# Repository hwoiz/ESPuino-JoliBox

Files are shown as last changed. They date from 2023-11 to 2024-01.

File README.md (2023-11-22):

# Jolibox
## Ein mit RFID-Karten steuerbarer Audioplayer
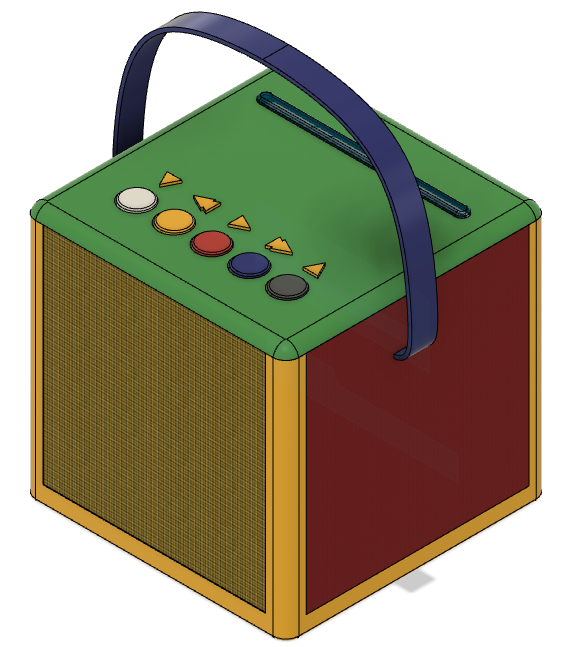
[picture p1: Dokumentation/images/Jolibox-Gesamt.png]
Jolibox


Auf Bais der [Software ESPuino](https://forum.espuino.de/c/software/7) und der [Hardware (ESPuino-mini 4Layer + D32 pro FePo)](https://forum.espuino.de/t/espuino-mini-4layer/1661) von [biologist79](https://github.com/biologist79/ESPuino) habe ich einen kindgerechten Auidioplayer entwickelt. 

Die Druckdateien für das Gehäuse wurden mit der kostenlosen Version von Fusion 360 erstellt und anschließend mit einem 3D-Drucker ausgedruckt. So entstand ein 'kinderleicht' zu bedienender Audioplayer für meine 2-jährige Enkeltochter. Die Titelauswahl kann sie mit den programmierten RFID-Karten selbst vornehmen. 

Die gesamte Administration des Audioplayers erfolgt über eine Webseite mit einem beliebigen Browser durch die Eltern.

---

- [Benutzerhandbuch](Dokumentation/Benutzerhandbuch.md)
- [Technikhandbuch](Dokumentation/Technikhandbuch.md)
- [Gehäuse Konstrutiondaten](Dokumentation/Gehäuse.md)
- [Deutsche Übersetzung der README.md aus dem biologist79-Repository](Dokumentation/README.md-biologist.md)

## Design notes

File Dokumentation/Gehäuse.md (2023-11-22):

# Gehäuse
Um die Elektronik ansprechend und kindgerecht zu verpacken, wurde ein Gehäuse für den 3D-Druck entwickelt.
JoliBox

Die zum Druck notwendigen STL-Dateien wurden mit der Lizenz von Fusion 360 für Privatanweder erstellt. Diese kann nach einer Registrierung [hier](https://www.autodesk.de/products/fusion-360/personal-form) kostenlos heruntergeladen werden.

Zur leichteren Verschraubung der Bauteile wurden in die vorgesehenen Löcher M3-Messing-Einpressmuttern ([z.B. Amazon-Link](https://www.amazon.de/STCRERAG-Gewindeeinsatz-Einpressmutter-Schmelzgewinde-Kunststoffteile/dp/B095VW7GBW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)) mit dem Lötkolben eingeschmolzen. 

Die vollständigen Konstruktionsdaten zum Import in Fusion 360 stelle ich [hier](Gehäuse/ESPuino-Jolibox.f3z) zur Verfügung. Dort kann dann die Konstruktion der Box an die eigenen Wünsche angepasst werden.

Der Druck erfolgte mit PLA auf einem Anycubic i3 Mega. 

Falls die Box ohne Anpassungen gedruckt werden soll, stelle ich nachfolgend die dafür notwendigen STL-Dateien zur Verfügung. Sie müsen noch für den verwendeten 3D-Drucker in gcode-Dateien umgewandelt werden. Hierfür kann die kostenlose Software [Cura](https://ultimaker.com/software/ultimaker-cura/) oder [PrusaSlicer](https://www.prusa3d.com/de/page/prusaslicer_424/) verwendet werden.

### Box Unterteil
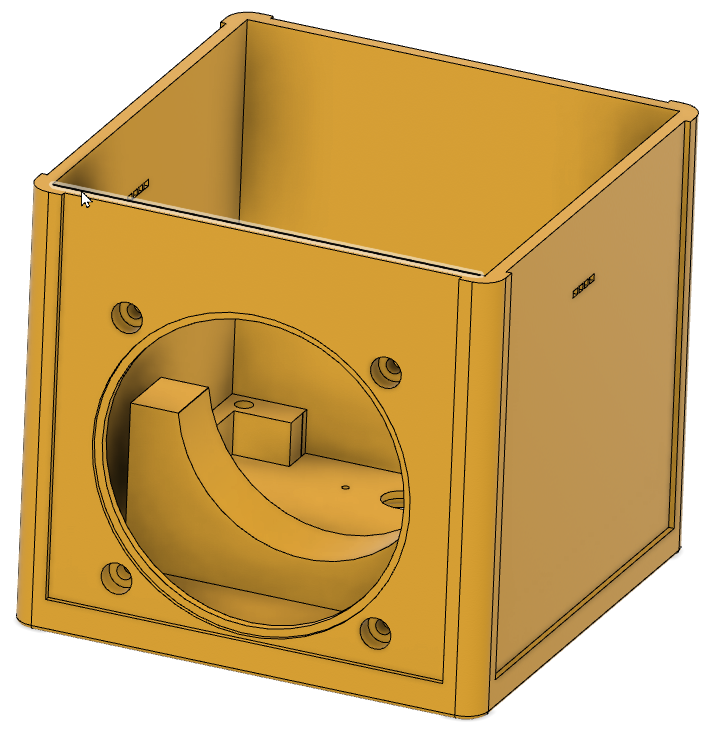
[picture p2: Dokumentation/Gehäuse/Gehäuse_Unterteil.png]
Box-Unterteil

>[Gehäuse_Unterteil.stl](Gehäuse/Gehäuse_Unterteilteil.stl)

> :information_source: Die vier senkrechten Seiten der Box wurden mit 1mm starkem, farblich unterschiedlichem Filz beklebt ([z.B. Amazon-Link](https://www.amazon.de/gp/product/B01MDNM6D7/ref=ppx_yo_dt_b_search_asin_title?ie=UTF8&psc=1)). Der Filz wurde mit Sprühkleber befestigt. 
> Alternativ können auch entsprechende Abdeckungen mit dem 3D-Drucker erstellt werden. 
 
 ---
### Box Oberteil
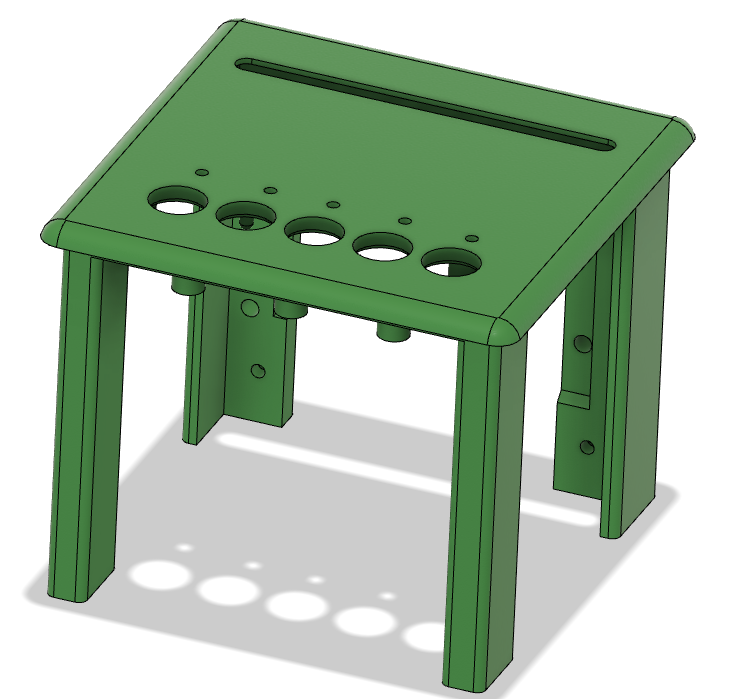
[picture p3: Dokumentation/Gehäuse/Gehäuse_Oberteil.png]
Box-Oberteil

>[Gehäuse_Oberteil.stl](Gehäuse/Gehäuse_Unterteilteil.stl)

---
### LED-Halter
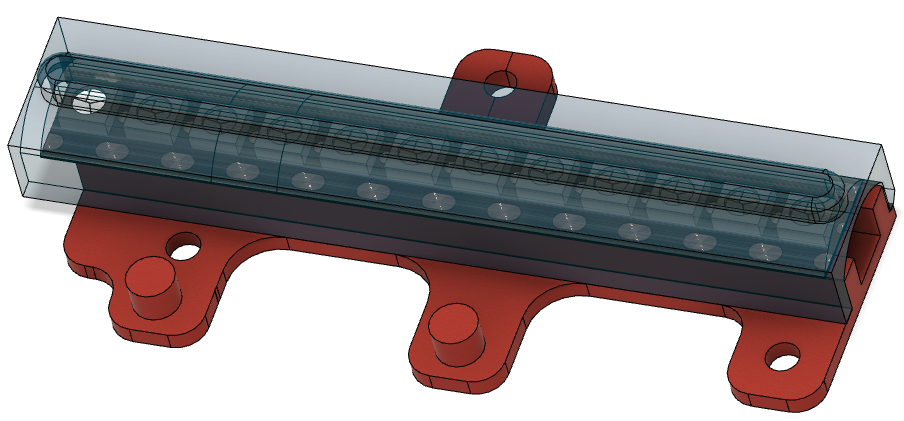
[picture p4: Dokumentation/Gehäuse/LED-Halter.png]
LED-Halter

>[LED-Halter-Aussen.stl](Gehäuse/LED-Halter-Aussen.stl) -  :warning: Transparentes PLA verwenden

>[LED-Halter-Deckel.stl](Gehäuse/LED-Halter-Deckel.stl)

Der Halter nimmt einen Abschnitt von 12 LED eines RGB LED-Streifen WS2812B mit 144 LED/m auf ([z.B. Amazon-Link](https://www.amazon.de/gp/product/B08P6XN49P/ref=ppx_yo_dt_b_search_asin_title?ie=UTF8&psc=1)).

---
### Tastatur-Halter
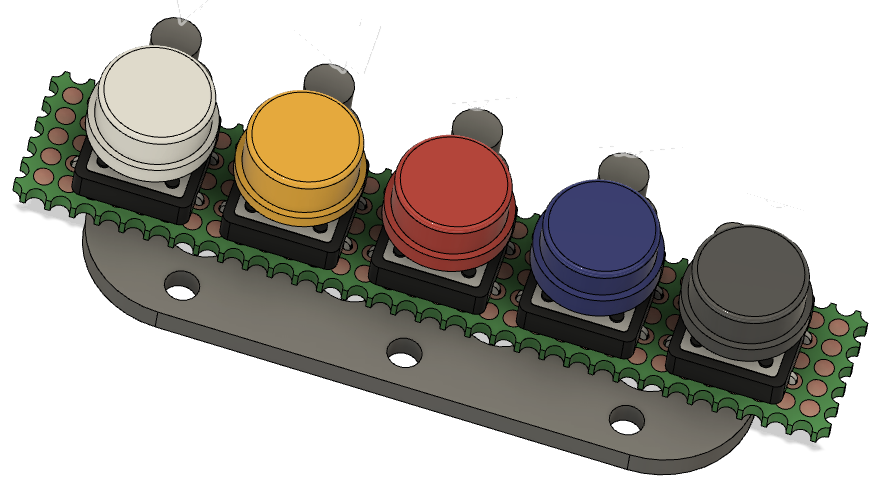
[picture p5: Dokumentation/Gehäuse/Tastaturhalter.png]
Tastatur-Halter

>[Tastaturhalter.stl](Gehäuse/Tastaturhalter.stl)

---
### Tastatur-Symbole
Tastatur-Symbole
>[Symbole.stl](Gehäuse/Symbole.stl)

---
### Tragegurtverschluss
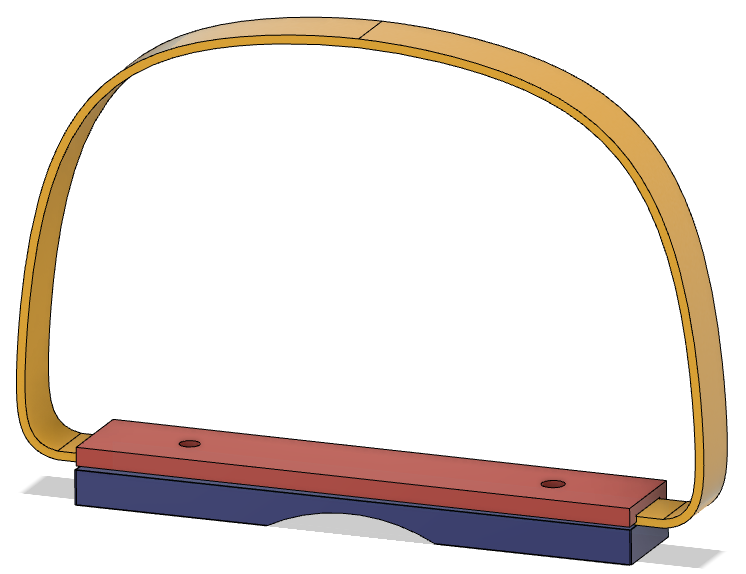
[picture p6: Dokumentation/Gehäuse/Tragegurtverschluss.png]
Tragegurtverschluss

>[Tragegurtverschluss-oben.stl](Gehäuse/Tragegurtverschuss-oben.stl)

>[Tragegurtverschluss-unten.stl](Gehäuse/Tragegurtverschluss-unten.stl)

> :information_source: Für den Tragegurt wurde farbiges Gurtband von 10mm Breite und 1,5mm Stärke benutzt ([z.B. Amazon-Link](https://www.amazon.de/gp/product/B0BNJCMKBM/ref=ppx_yo_dt_b_search_asin_title?ie=UTF8&psc=1)).

---
### Träger-Stromversorgung
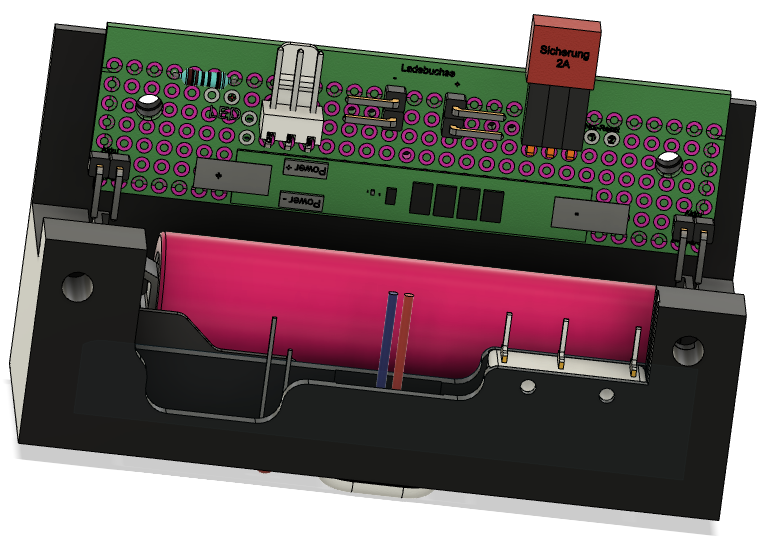
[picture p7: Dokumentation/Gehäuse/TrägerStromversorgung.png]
Träger-Stromversorgung

>[TrägerStromversorgung.stl](Gehäuse/TrägerStromversorgung.stl)

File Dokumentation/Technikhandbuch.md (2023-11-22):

# Technikhandbuch
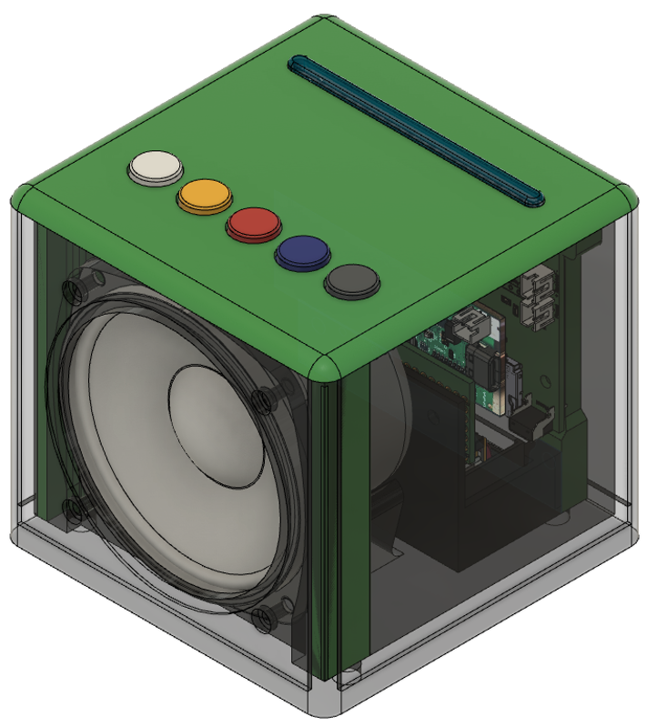
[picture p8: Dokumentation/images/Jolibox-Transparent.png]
Jolibox


Harald Woizischke
info@woizischke.de

Technische Beschreibung einer Kinder-Musikbox auf Basis eines ESP32. 
Kinder können die Musik oder Hörspiele mit Rfid-Tags auswählen.
Die Konfiguration der Box erfolgt über eine Webschnittstelle im Browser.

# Einleitung
Dieses Dokument beschreibt alle zum Bau notwendigen Komponenten.
Die Gehäuseteile wurden mit Autocad Fusion 360 entworfen und mit einem 3D-Drucker in PLA gedruckt.
Als Systemplattform wurde die Lösung von Torsten Stauder (biologist) gewählt. Einzelheiten zum Projekt sind im Internet unter https://forum.espuino.de/ zu finden.

# Hardware
## Elektronik Baugruppen
Es wurden folgende Baugruppen und Bauteile zur Realisierung eingesetzt.
- ESPuino-mini 4Layer von biologist - https://forum.espuino.de/t/espuino-mini-4layer/1661/1
- D32 pro FePo. von biologist - https://forum.espuino.de/t/develboard-d32-pro-lifepo4/1109
- Tastatur auf Lochrasterplatine. Tasten aus Set - https://de.aliexpress.com/item/1005003510575948.html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
- Akku 18650 3.2V 2.000mAh LiFePO4 - https://www.eremit.de/p/18650-3-2v-2-000mah-lifepo4
- Zusatzplatine für Akkuhalterung auf Lochrasterplatine
- Visaton vs-f8sc/8 Lautsprecher - https://www.amazon.de/dp/B0056BQXCW?psc=1&ref=ppx_yo2ov_dt_b_product_details
- RFID-Reader RC522
- 12 LED aus 5v RGB LED-Streifen WS2812B 144 Pixel/m - https://www.amazon.de/gp/product/B08P6XN49P/ref=ppx_yo_dt_b_search_asin_title?ie=UTF8&psc=1 
- 3mm LED rot für Ladeanzeige
- USB-C Ladebuchse - https://de.aliexpress.com/item/1005004913934656.html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
- Micro-Switch für Not-Reset - https://www.amazon.de/VILLCASE-Endschalter-Scharnierhebel-Steuerung-Mikroschalter/dp/B08H52SDG2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 
- Amazon BASIC PLA - https://www.amazon.de/gp/product/B07CTQDQ77/ref=ppx_yo_dt_b_search_asin_title?ie=UTF8&psc=1

## ESPuino-mini_4Layer
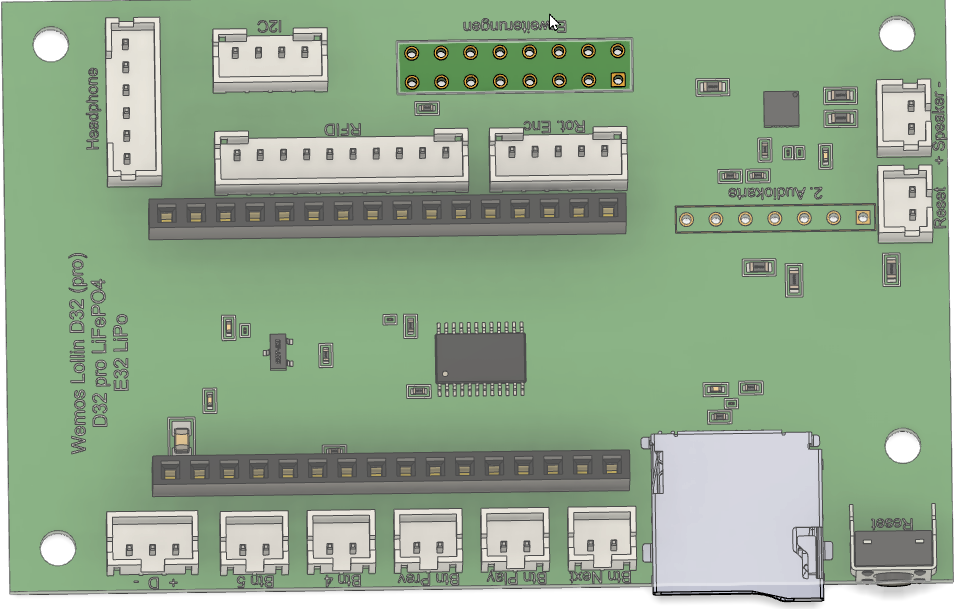
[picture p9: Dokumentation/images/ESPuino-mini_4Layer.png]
ESPuino-mini_4Layer
 
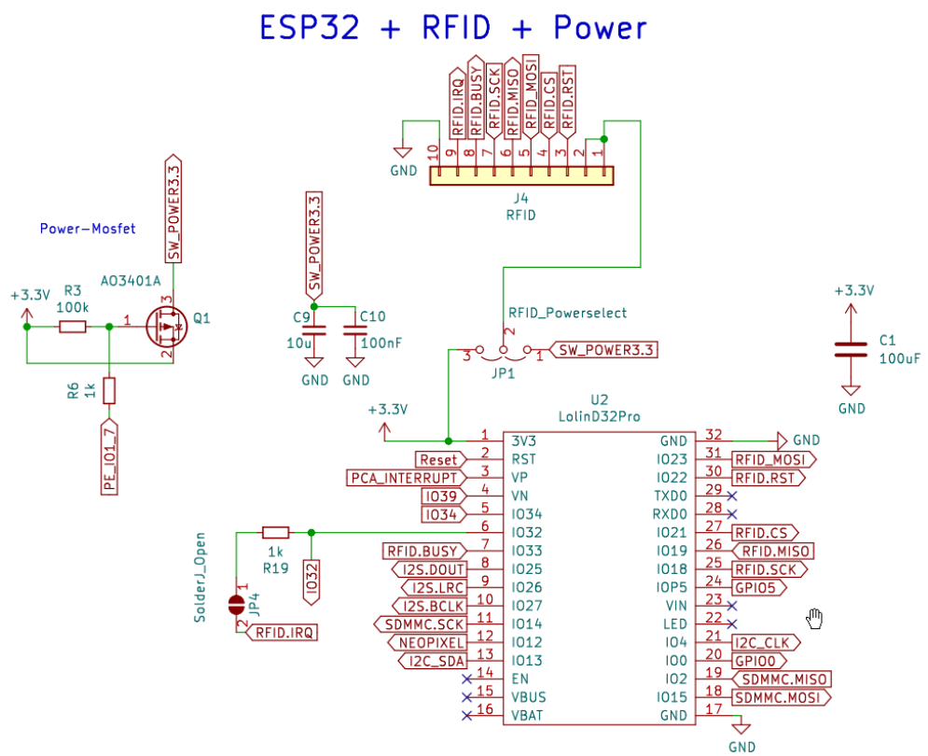
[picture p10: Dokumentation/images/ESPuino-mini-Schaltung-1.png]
Espuino-mini_1
 
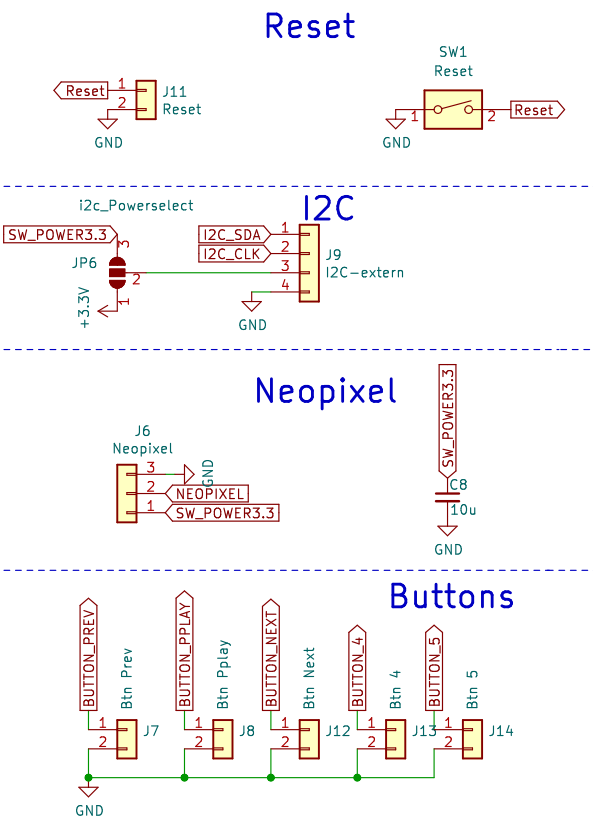
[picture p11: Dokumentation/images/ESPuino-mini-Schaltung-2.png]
Espuino-mini_2
 
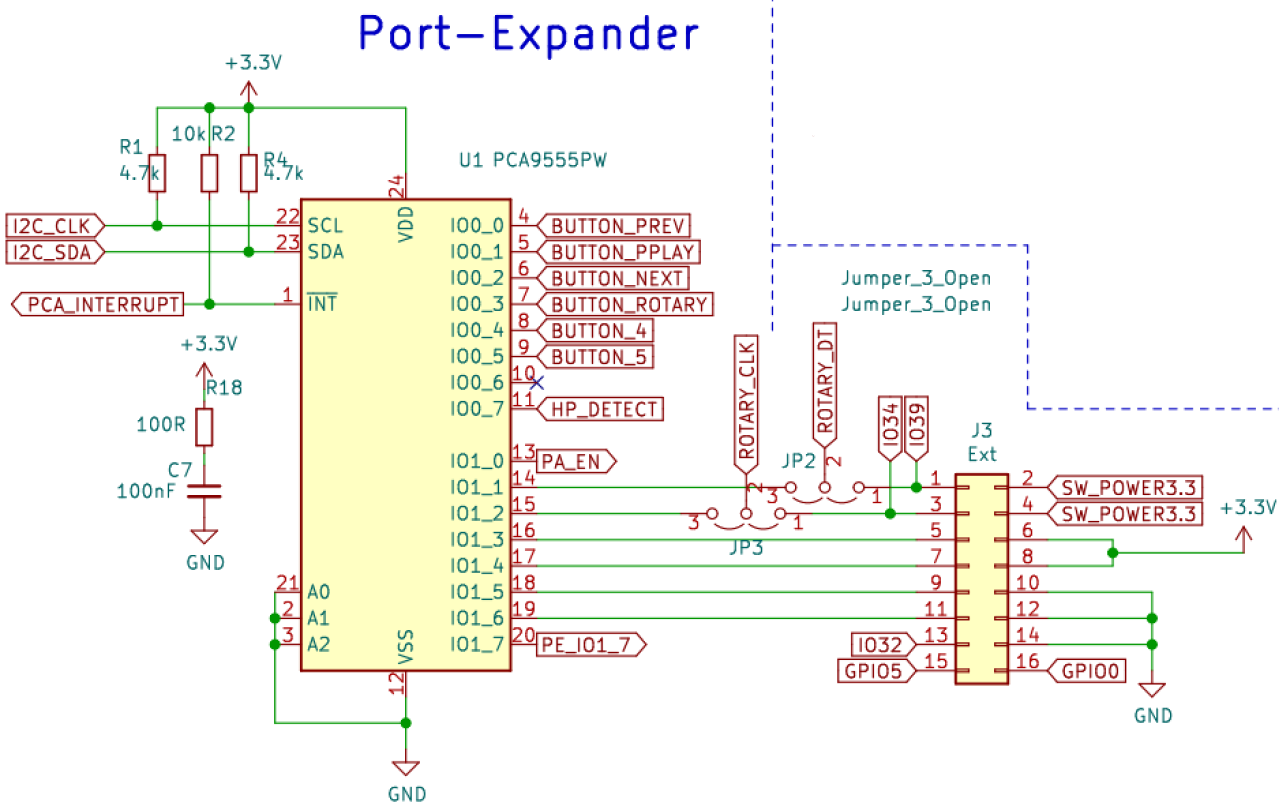
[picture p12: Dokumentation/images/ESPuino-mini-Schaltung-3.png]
Espuino-mini_3
 
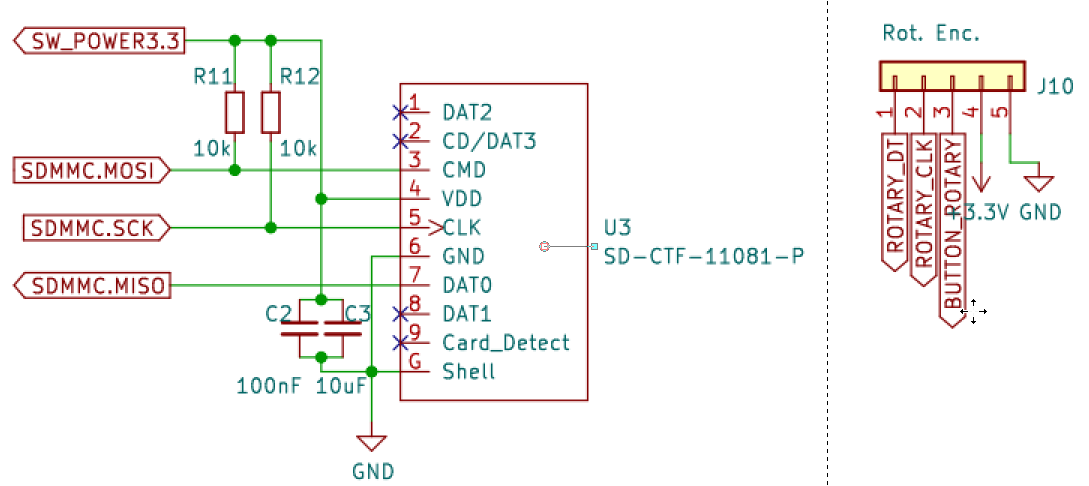
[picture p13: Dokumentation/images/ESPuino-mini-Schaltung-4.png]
Espuino-mini_4
 
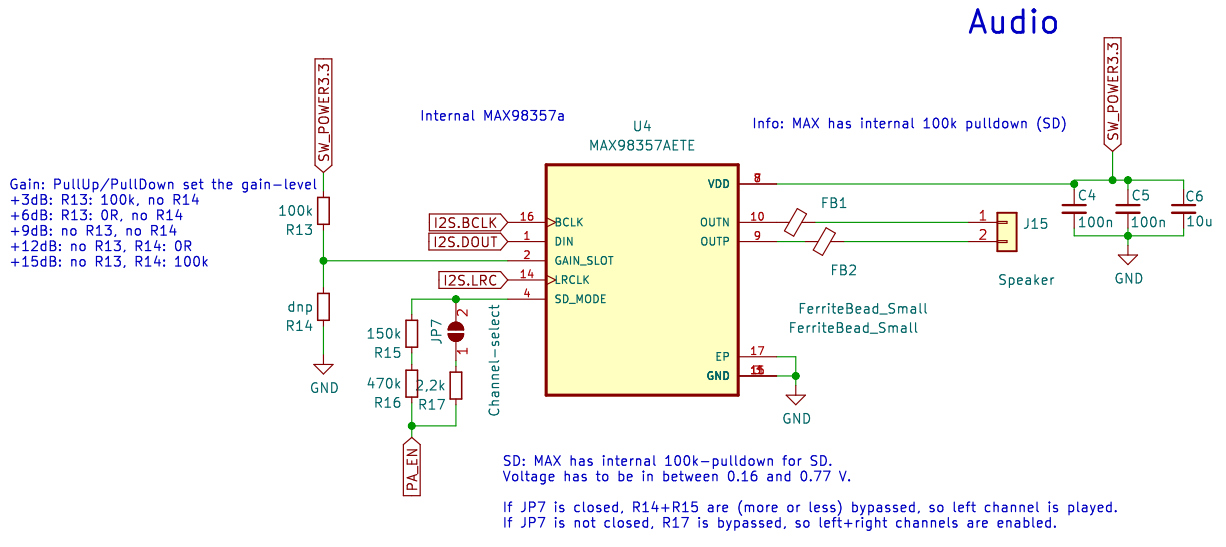
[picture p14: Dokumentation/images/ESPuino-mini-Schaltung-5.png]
Espuino-mini_5
 
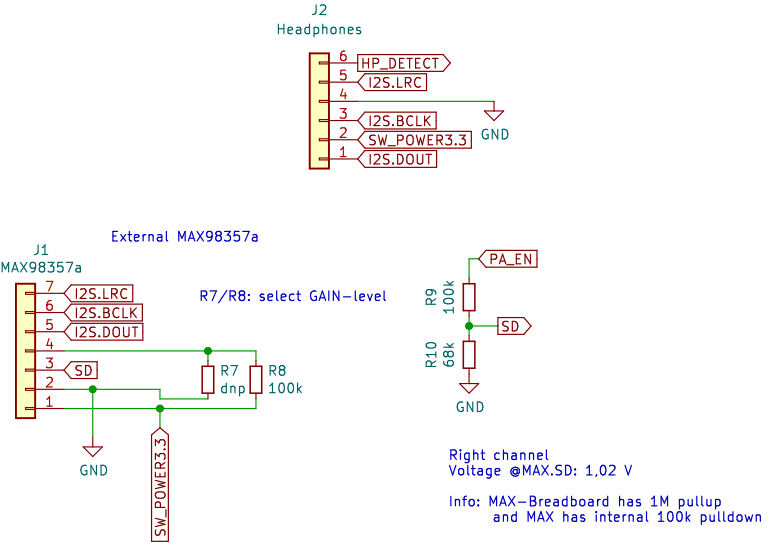
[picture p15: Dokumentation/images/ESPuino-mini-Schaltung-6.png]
Espuino-mini_6
 
 ** Hardware Konfiguration **
Auf Unterseite der Platine befinden sich mehrere Lötbrücken (JP1 bis JP7, JP5 fehlt), die konfiguriert werden können bzw. müssen. Sie werden im Folgenden beschrieben. Kursiv markiert ist die Konfiguration, die aus meiner Sicht „standard“ ist (sofern anwendbar):
JP1: *Schließe* 1+2 wenn du kein LPCD benötigst (Normalzustand). Schließe 2+3, wenn du LPCD benötigst. Auswirkung: Für LPCD wird das RFID-Modul dauerhaft mit Spannung versorgt, so dass eine etwas höhere Stromaufnahme im Deepsleep anfällt. Vergisst du JP1 komplett, so wird dein RFID-Reader nicht funktionieren, da er (egal wann) keine Versorgungsspannung erhält. Hinweis: Willst du dieses Feature nutzen, dann musst du auch die Brücke von JP4 schließen. Sollte dir unklar sein, was LPCD bedeutet, so findest du hier die Erklärung: 📗 [Was ist LPCD und wie funktioniert es?](https://forum.espuino.de/t/was-ist-lpcd-und-wie-funktioniert-es/1664).
**Pflicht!**
JP2: *Schließe* 1+2 wenn DT des Drehencoders auf GPI(O)39 geroutet werden soll. Schließe 2+3, wenn GPIO39 frei sein soll und DT stattdessen auf dem Port-Expander (109) landen soll. Stand jetzt (01/2023) macht ausschließlich GPIO Sinn, da ESPuino hier den Port-Expander noch nicht unterstützt. Vergisst du JP2 komplett, so funktioniert die Drehbewegung deines Drehencoders nicht (sofern du diesen verwendest).
**Pflicht wenn ein Drehencoder verwendet wird!**
JP3: Schließe 1+2 wenn CLK des Drehencoders auf GPIO34 geroutet werden soll. Schließe 2+3, wenn GPIO34 frei sein soll und DT stattdessen auf dem Port-Expander (110) landen soll. Stand jetzt (01/2023) macht ausschließlich GPIO Sinn, da ESPuino hier den Port-Expander noch nicht unterstützt. Vergisst du JP3 komplett, so funktioniert die Drehbewegung deines Drehencoders nicht (sofern du diesen verwendest).
**Pflicht wenn ein Drehencoder verwendet wird**
JP4: Schließe diese Brücke, wenn du LPCD verwenden möchtest (beachte dafür unbedingt auch JP1!).
**Optional!**
JP5: Gibt es nicht (mehr).
JP6: *Schließe* 1+2 wenn der 3.3 V-Pin am externen I2C-Konnektor dauerhaft mit Spannung versorgt werden soll. Schließe 2+3, wenn er im Deepsleep des ESP32 spannungslos geschaltet werden soll. Da so gut wie niemand bisher externe I2C-Devices anschließt, hat ein Vergessen der Brücke erstmal keine Auswirkungen. Hintergrund der Konfigurationsmöglichkeit ist [hier](https://forum.espuino.de/t/espuino-minid32-pro-lolin-d32-d32-pro-mit-sd-mmc-und-port-expander-smd/866/53) beschrieben.
**Optional!**
JP7: Wenn du einen zweiten MAX98357a 90 anschließen möchtest, dann solltest du diese Brücke schließen, so dass der aufgelötete MAX98357a nur den linken Kanal ausgibt. Der zweite MAX98357a wird automatisch den rechten Kanal ausgeben, so dass du stereo über zwei Lautsprecher nutzen kannst. Achte in diesem Falle auch drauf, dass du PLAY_MONO_SPEAKER auskommentieren musst.
**Optional!**

### Kabelplan

#### RFID-Reader 5180
```
Stecker         Farbe           PN5180
5V     ------   sw   ---------  5V
3.3V   ------   rt   ---------  3.3	
RST    ------   ws   ---------  RST
CS     ------   ge   ---------  NSS
MOSI   ------   or   ---------  MOSI
MISO   ------   gn   ---------  MISO
SCK    ------   bl   ---------  SCK
BSY    ------   vi   ---------  BUSY
IRQ    ------   gr   ---+  +--  GND
GND    ------   br   ---|--+    GPIO
                        +----   IRQ
                                AUX
                                REQ 
```

#### Rotary-Encoder
```
Stecker     Farbe           Encoder
DT  -----   sw   -+    +-  CLK
CLK -----   rt   -+----+-  DT
BTN -----   ws   --------  SW
3.3 -----   ge   --------  +
GND -----   or   --------  GND
```

#### NeoPixel
```
Stecker     Farbe          LED-Stripe	
-   -----   rt    -------  -	
D1  -----   sw    -------  D0
+   -----   ge    -------  5V
```

## D32_FePo_rev4
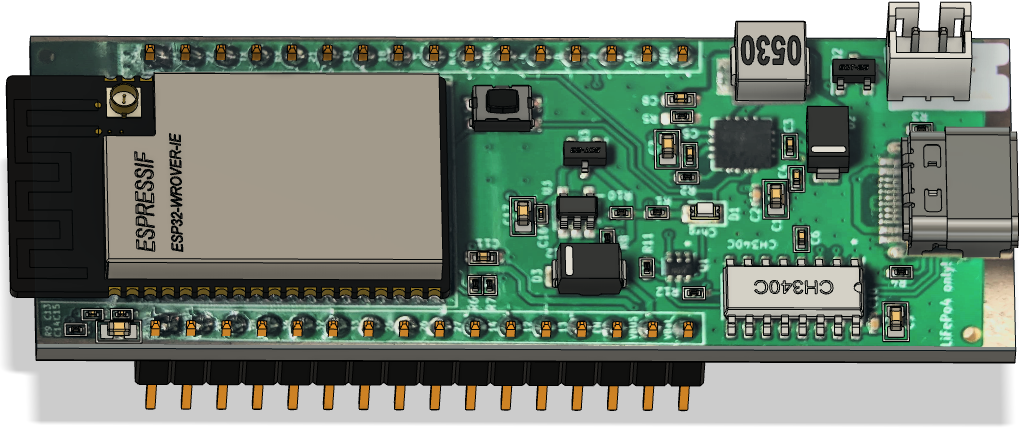
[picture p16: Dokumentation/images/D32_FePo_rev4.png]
D32_FePo_rev4

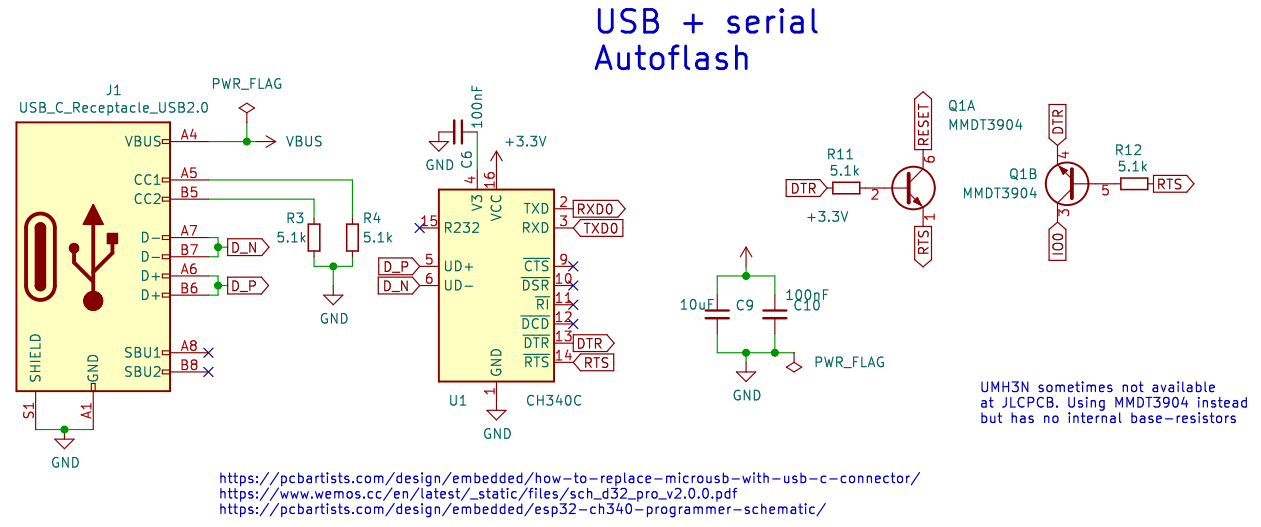
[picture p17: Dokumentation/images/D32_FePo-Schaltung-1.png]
D32_FePo-Schaltung

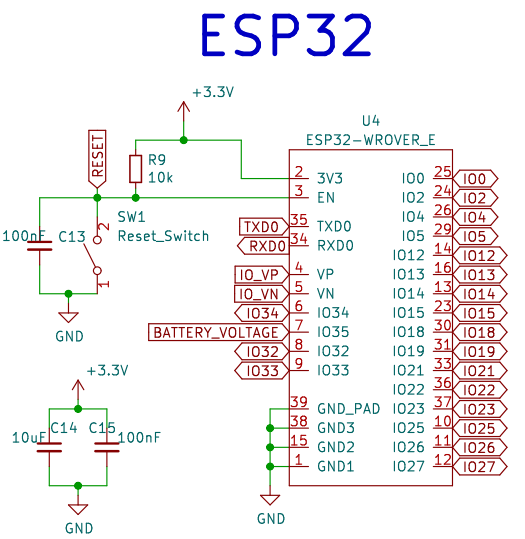
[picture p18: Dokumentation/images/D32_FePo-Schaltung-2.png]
D32_FePo-Schaltung

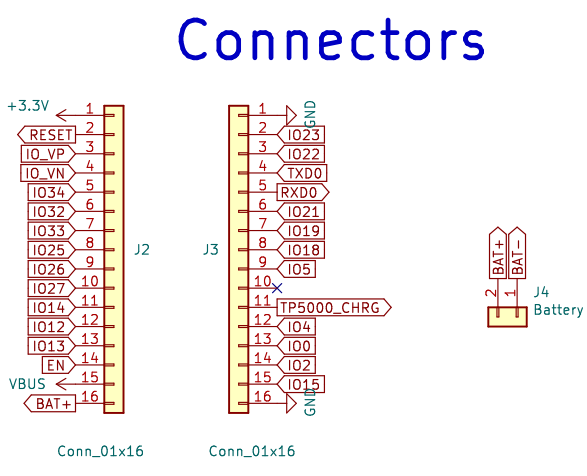
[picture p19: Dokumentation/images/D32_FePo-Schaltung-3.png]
D32_FePo-Schaltung

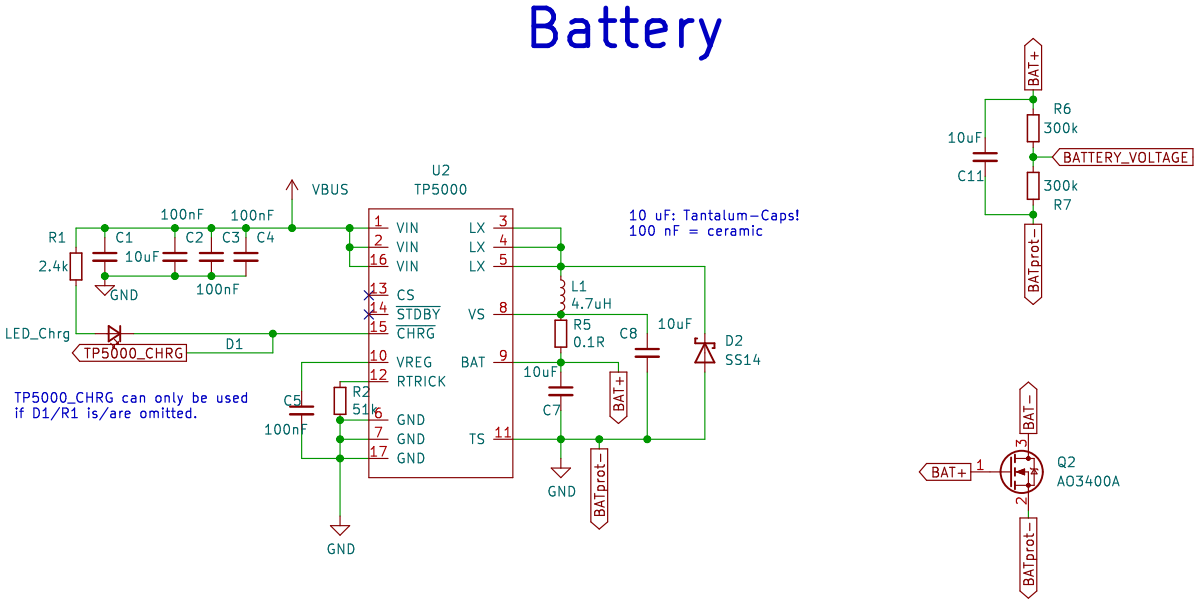
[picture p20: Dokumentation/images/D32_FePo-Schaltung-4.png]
D32_FePo-Schaltung

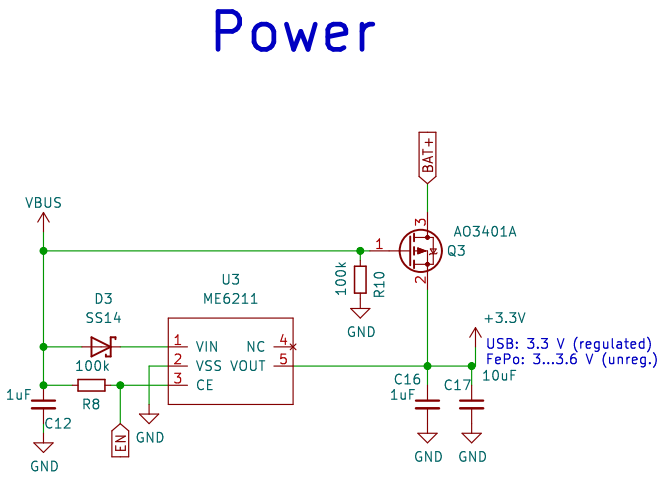
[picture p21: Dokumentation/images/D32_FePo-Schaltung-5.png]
D32_FePo-Schaltung

> :warning:	**Wichtig**
> Auf keinen Fall darf ein LiPo-Akku angeschlossen werden. Der TP5000 unterstützt, wenn man ihn entsprechend beschaltet, zwar auch LiPo, ich habe ihn (aus Komplexitäts- und Platzgründen) jedoch fest auf FePo eingestellt. 
> Das Hauptproblem ist jedoch: Wird ein LiPo-Akku angeschlossen, so geht, je nach Akkuspannung (Ladung), mindestens das ESP32-Modul kaputt, weil die Spannung vom Akku (wie oben beschrieben und im Schaltplan sichtbar) nicht durch den Festspannungsregler läuft und Spannungen >3,6 V vom ESP32 nicht toleriert werden!!! LiPo liefert jedoch bis zu 4,2 V. Das Umgehen des Festspannungsreglers habe ich deswegen so gemacht, weil es die FePo-Spannung, die ja schon passt, unerwünscht reduzieren würde, wenn die Batteriespannung ebenfalls den gleichen Weg wie USB ginge.

## Zusatzplatine Akkuhalterung
Für den Anschuss von der Lade LED, dem Not-Reset-Schalter, der Ladebuchse und der Schutzschaltung für den Akku wurde eine Lochrasterplatine verwendet.
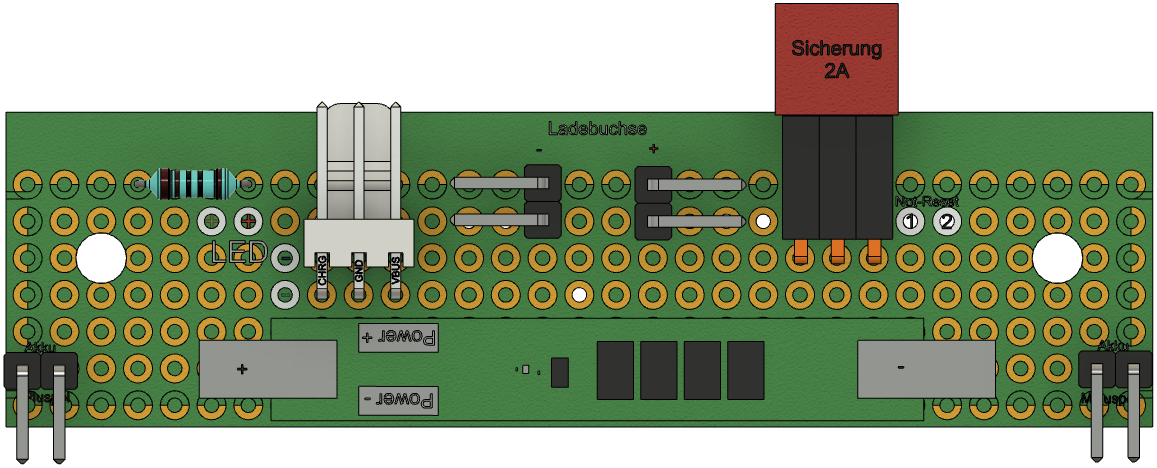
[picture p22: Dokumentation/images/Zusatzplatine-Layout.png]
Zusatzplatine-Layout

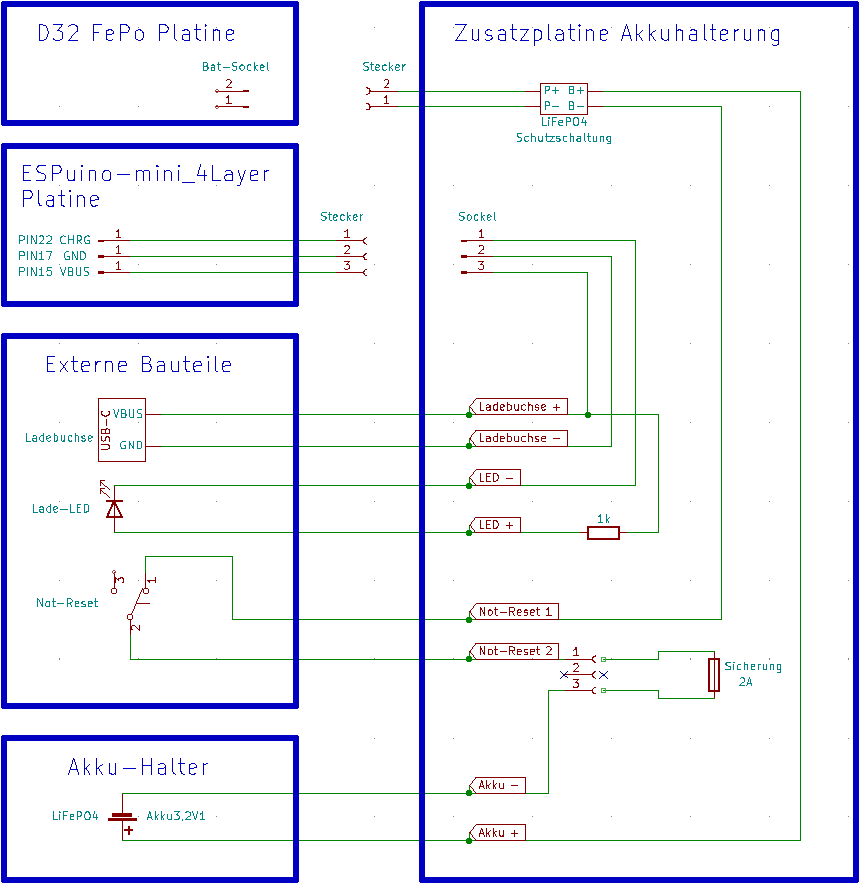
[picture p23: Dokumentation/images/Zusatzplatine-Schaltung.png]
Zusatzplatine-Schaltung


## Tastatur
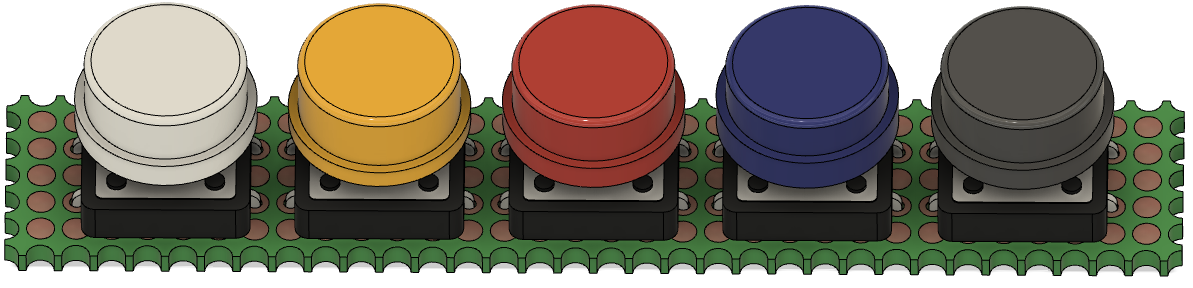
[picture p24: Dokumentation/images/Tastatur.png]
Tastatur


# Software
## Dynamisches Button-Layout
Ursprünglich war in der Firmware des ESPuino fest verankert, dass die Bedienung über drei Tasten und einem Drehencoder zu erfolgen hat. Die Bedienung/Bedeutung der jeweiligen Tasten war dabei vorgegeben. Dies hat sich nun geändert: Tasten können nun wahlweise hinzugefügt und entfernt werden. Auch ist der Drehencoder nun optional.
An dieser Stelle sei erwähnt, dass das von mir empfohlene (und benutzte) Layout weiterhin drei Taster und ein Drehencoder ist. 
- Als neue Direktive in settings.h ist USEROTARY_ENABLE hinzugekommen. Wird kein Drehencoder gebraucht, so kann dies deaktiviert werden. Hinweis: Ist dies der Fall, so muss in der jeweiligen Develboard-spezifischen Config unbedingt WAKEUP_BUTTON angepasst werden.
- Mit dem eben bereits angesprochenen WAKEUP_BUTTON kann festgelegt werden, mit welcher Taste der ESPuino wieder aus dem Tiefschlaf geholt werden soll. Es ist an dieser Stelle darauf zu achten, dass nur sog. RTC-GPIOs 1 (0, 4, 12, 13, 14, 15, 25, 26, 27, 32, 33, 34, 35, 36, 39) verwendbar sind. Es können an dieser Stelle direkt Zahlen reingeschrieben werden oder aber z.B. auch Namen wie DREHENCODER_BUTTON oder NEXT_BUTTON. Soll dieses Feature deaktiviert werden, so ist eine 99 zu setzen. Nicht auskommentieren!
- In der Develboard-spezifischen Config sind die Tasten BUTTON_4 und BUTTON_5 hinzugekommen. Per Voreinstellung sind sie deaktiviert (99). Im Gegenzug können jedoch auch NEXT_BUTTON, PREVIOUS_BUTTON oder PAUSEPLAY_BUTTON wahlweise aktiviert oder deaktiviert werden.
- In settings.h können den Tastern nun beliebige Aktionen zugewiesen werden. Hierbei ist zu unterscheiden, ob es sich um eine Tastenkombination aus zwei Tasten (MULTI_n_SHORT) oder um eine einzige Taste (BUTTON_n_SHORT oder BUTTON_n_LONG) handelt. D.h. jeder einzelnen Taste kann man eine Aktion für kurzen Tastendruck und eine für langen Tastendruck zuweisen.
- Möchte man einer Taste keine Aktion zuweisen, so ist die Direktive CMD_NOTHING zu setzen. Dies muss entsprechend für einen kurzen und/oder langen Tastendruck gemacht werden.

Möchte man einer Taste eine Aktion zuweisen, so sind folgende Aktionen möglich (siehe values.h):

|Kommando	|Beschreibung|
------------|------------|
|CMD_LOCK_BUTTONS_MOD	|Sperrt alle Tasten und gibt sie [theoretisch] wieder frei. Macht als Tastenbelegung eher nicht so viel Sinn, da man mit gesperrten Tasten keine Tastenaktion mehr auslösen kann. Ist eher eine Aktion für Modifikationskarten.
|CMD_SLEEP_TIMER_MOD_15	|Schaltet sich nach 15 Minuten aus und LEDs werden gedimmt
|CMD_SLEEP_TIMER_MOD_30	|Schaltet sich nach 30 Minuten aus und LEDs werden gedimmt
|CMD_SLEEP_TIMER_MOD_60	|Schaltet sich nach 60 Minuten aus und LEDs werden gedimmt
|CMD_SLEEP_TIMER_MOD_120	|Schaltet sich nach 120 Minuten aus und LEDs werden gedimmt
|CMD_SLEEP_AFTER_END_OF_TRACK	|Schaltet sich nach Ende des Titels aus und LEDs werden gedimmt
|CMD_SLEEP_AFTER_END_OF_PLAYLIST	|Schaltet sich nach Ende der Playlist aus und LEDs werden gedimmt
|CMD_SLEEP_AFTER_5_TRACKS	|Schaltet sich nach Ende von fünf Titeln aus und LEDs werden gedimmt
|CMD_REPEAT_PLAYLIST	|Aktuelle Playlist wird endlos wiederholt
|CMD_REPEAT_TRACK	|Aktueller Titel wird endlos wiederholt
|CMD_DIMM_LEDS_NIGHTMODE	|Dimmt LEDs in Nachtmodus
|CMD_TOGGLE_WIFI_STATUS	|Schaltet WLAN an/aus
|CMD_TOGGLE_BLUETOOTH_SINK_MODE	|Schaltet den Bluetooth-Modus an/aus, bei dem man zu ESPuino streamen kann (z.B. von einem Handy).
|CMD_TOGGLE_BLUETOOTH_SOURCE_MODE	|Schaltet den Bluetooth-Modus an/aus, bei dem man von ESPuino zu einem externen Lautsprecher oder einem Kopfhörer streamen kann.
|CMD_ENABLE_FTP_SERVER	|Schaltet FTP-Server an (aus geht nicht)
|CMD_PLAYPAUSE	|Wechsel zwischen Pause und Play
|CMD_PREVTRACK	|Vorheriger Titel der aktuellen Playlist
|CMD_NEXTTRACK	|Nächster Titel der aktuellen Playlist
|CMD_FIRSTTRACK	|Sprung zu erstem Titel der aktuellen Playlist
|CMD_LASTTTRACK	|Sprung zu letztem Titel der aktuellen Playlist
|CMD_VOLUMEINIT	|Stellt aktuelle Lautstärke auf Lautstärke nach dem Start ein
|CMD_VOLUMEUP	|Erhöht Lautstärke um eine Einheit
|CMD_VOLUMEDOWN	|Reduziert Lautstärke um eine Einheit
|CMD_MEASUREBATTERY	|Startet Messung der Akkuspannung (wird über Log, Neopixel und MQTT anschließend ausgegeben)
|CMD_SLEEPMODE	|Schaltet ESPuino sofort aus
|CMD_SEEK_FORWARDS	|Springt n Sekunden nach vorne im Titel (Dauer in settings.h konfigurierbar
|CMD_SEEK_BACKWARDS	|Springt n Sekunden nach hinten im Titel (Dauer in settings.h konfigurierbar

# Erstkonfiguration der Jolibox

Nach der Übernahme des Sourcecode von biologist sind in folgenden Dateien einige Konfigurationen anzupassen.

## plattformio.ini

```
13: default_envs = lolin_d32_pro_sdmmc_pe  // Ist als Default voreingestellt
```
## settings.h

```34: #define PORT_EXPANDER_ENABLE``` Zeile aktivieren
```44: #define PLAY_MONO_SPEAKER``` Zeile aktivieren
```49: #define PLAY_LAST_RFID_AFTER_REBOOT``` Zeile aktivieren
```57: #define SAVE_PLAYPOS_BEFORE_SHUTDOWN``` Zeile aktivieren
```58: #define SAVE_PLAYPOS_WHEN_RFID_CHANGE``` Zeile aktivieren
```74: #define RFID_READER_TYPE_MFRC522_SPI``` Zeile auskommentieren
```76: #define RFID_READER_TYPE_PN5180``` Zeile aktivieren

Zeilen 124 bis 152 mit nachfolgenden Zeilen ersetzen

```
    #define BUTTON_0_SHORT    CMD_NEXTTRACK                   // Nächster Titel              	
    #define BUTTON_1_SHORT    CMD_PREVTRACK                   // vorheriger Titel              	
    #define BUTTON_2_SHORT    CMD_PLAYPAUSE                   // Play/Pause             	
    #define BUTTON_3_SHORT    CMD_NOTHING                     // nicht definiert
    #define BUTTON_4_SHORT    CMD_SEEK_BACKWARDS              // um 30 Sek. zurückspulen 
    #define BUTTON_5_SHORT    CMD_SEEK_FORWARDS               // um 30 Sek. vorspulen
    
    #define BUTTON_0_LONG     CMD_LASTTRACK                   // letzter Titel der Playliste
    #define BUTTON_1_LONG     CMD_FIRSTTRACK                  // erster Titel der Playliste
    #define BUTTON_2_LONG     CMD_SLEEPMODE                   // Ausschalten
    #define BUTTON_3_LONG     CMD_SLEEPMODE                   // nicht definiert
    #define BUTTON_4_LONG     CMD_VOLUMEUP                    // Lautstärke erhöhen
    #define BUTTON_5_LONG     CMD_VOLUMEDOWN                  // Lautstärke verringern
 
    #define BUTTON_MULTI_01   CMD_REPEAT_TRACK                // Titel endlos wdhl. 
    #define BUTTON_MULTI_02   CMD_ENABLE_FTP_SERVER           // FTP-Server aktivieren 
    #define BUTTON_MULTI_03   CMD_NOTHING                     // nicht definiert 
    #define BUTTON_MULTI_04   CMD_TOGGLE_BLUETOOTH_SINK_MODE  // Bluetooth-Modus an/aus
    #define BUTTON_MULTI_05   CMD_DIMM_LEDS_NIGHTMODE         // LED auf Nachtmodus 
    #define BUTTON_MULTI_12   CMD_TELL_IP_ADDRESS             // IP-Adresse der Box ansagen
    #define BUTTON_MULTI_13   CMD_NOTHING                     // nicht definiert
    #define BUTTON_MULTI_14   CMD_NOTHING                     // nicht definiert
    #define BUTTON_MULTI_15   CMD_NOTHING                     // nicht definiert
    #define BUTTON_MULTI_23   CMD_NOTHING                	  // nicht definiert
    #define BUTTON_MULTI_24   CMD_SLEEP_TIMER_MOD_30          // Sleeptimer 30 Minuten 
    #define BUTTON_MULTI_25   CMD_NOTHING                	  // nicht definiert
    #define BUTTON_MULTI_34   CMD_NOTHING                     // nicht definiert
    #define BUTTON_MULTI_35   CMD_NOTHING                     // nicht definiert
    #define BUTTON_MULTI_45   CMD_TOGGLE_BLUETOOTH_SOURCE_MODE // Bluetooth-Kopfhörer 
```

```203: constexpr const char accessPointNetworkSSID[] = "Jolibox";``` Von  `ESPuino`  auf `Jolibox` ändern
```207: constexpr const char nameBluetoothSinkDevice[] = "Jolibox";```  Von `ESPuino` auf `Jolibox` ändern
```215: #define NUM_INDICATOR_LEDS 12 ``` Von `24` auf `12` ändern

## settings-lolin_d32_pro_sdmmc_pe.h

``` 95: #define POWER 115```  Wert von `32` auf `115` ändern

``` 97: #define INVERT_POWER```  Zeile aktivieren

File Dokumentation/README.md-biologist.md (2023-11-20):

# ESPuino – RFID-gesteuerter Audioplayer auf Basis von ESP32 mit I2S-DAC-Unterstützung

Deutsche Übersetzung der README.md aus dem biologist79-Repository](Dokumentation/README.md-biologist.md)

Stand 07.11.2023

## Forum

Der Autor biologist79 hat ein deutschsprachiges Forum aufgesetzt, welches mit reichlich Doku
  versehen ist. biologist würde es freuen, euch dort zu sehen: <https://forum.espuino.de>. Ihr könnt euch
  dort mit eurem Github-Login einloggen, jedoch auch "normal" anmelden. Dokumentation findet ihr
  insbesondere hier: <https://forum.espuino.de/c/dokumentation/anleitungen/10>.

## News

> :warning: Bis Ende Oktober 2023 hat ESPuino das Framework von ESP32-Arduino1 auf ESP32-Arduino2 umgestellt. Dies brachte viele Verbesserungen mit sich, aber wie sich herausstellte, läuft diese Version aufgrund von Speicherbeschränkungen nicht mehr sicher auf ESP32 ohne PSRAM. Bitte achten Sie also unbedingt darauf, einen ESP32-WROVER zu verwenden!

## ESPuino - was ist das?

Die Grundidee von ESPuino besteht darin, RFID-Tags zur Steuerung eines Audioplayers zu verwenden. Sogar für Kinder ist dieses Konzept einfach: Legen Sie einen mit einem RFID-Tag versehenen Gegenstand (Karte, Spielzeugfigur usw.) auf eine Schachtel und die Musik beginnt mit der Wiedergabe von Inhalten von der SD-Karte oder dem Webradio. Legen Sie einen anderen RFID-Tag darauf und etwas anderes wird abgespielt. So einfach ist das.

Dieses Projekt basiert auf dem beliebten Mikrocontroller [ESP32 by
Espressif](https://www.espressif.com/en/products/hardware/esp32/overview). Warum? Es ist leistungsstark und die sofort einsatzbereite WLAN-Unterstützung ermöglicht weitere Funktionen wie einen integrierten Webserver, Smarthome-Integration über MQTT, Webradio und FTP-Server. Und sogar Bluetooth! Mein Hauptaugenmerk lag jedoch darauf, das Projekt auf eine modulare Basis zu portieren: Die MP3-Dekodierung erfolgt in Software und die digitale Musikausgabe erfolgt über das beliebte [I2S protocol](https://en.wikipedia.org/wiki/I%C2%B2S).
Wir brauchen also einen [DAC](https://en.wikipedia.org/wiki/Digital-to-analog_converter) , um daraus ein analoges Signal zu machen: Ich habe alle meine Tests mit
[MAX98357A](https://learn.adafruit.com/adafruit-max98357-i2s-class-d-mono-amp/pinouts),
[UDA1334](https://www.adafruit.com/product/3678),
[MS6324](https://forum.espuino.de/t/kopfhoererplatine-basierend-auf-ms6324-und-tda1308/1099/) und
[PCM5102a](https://github.com/biologist79/ESPuino/tree/master/PCBs/Headphone%20with%20PCM5102a%20and%20TDA1308)durchgeführt. Allgemeiner Hinweis: ESPuino nutzt die Bibliothek
[ESP32-audioI2S](https://github.com/schreibfaul1/ESP32-audioI2S/); also sollte alles, was mit dieser Bibliothek funktionieren soll, auch mit ESPuino funktionieren (aber vielleicht nicht sofort einsatzbereit). Dies gilt insbesondere für
[ES8388](https://github.com/schreibfaul1/ESP32-audioI2S/blob/master/examples/ESP32_ES8388/ESP32_ES8388.ino).

## Hardware-Setup

Sie könnten mit einem Steckbrett mit Überbrückungsdrähten beginnen, ich empfehle jedoch dringend , sofort mit einer Leiterplatte zu beginnen, die speziell für ESPuino entwickelt wurde. Es sind mehrere verfügbar, aber
[ESPuino-mini 4L (SMD)](https://forum.espuino.de/t/espuino-mini-4layer/1661) kann als die neueste Generation angesehen werden. Darüber hinaus benötigen Sie ein ESP32-Entwicklungsboard wie (oder ein anderes, das Pin-kompatibel ist):

- [D32 pro LiFePO4](https://forum.espuino.de/t/esp32-develboard-d32-pro-lifepo4/1109)
- [E32 LiPo](https://forum.espuino.de/t/esp32-develboard-e32-lipo/1135)
- [Wemos Lolin D32 pro](https://www.wemos.cc/en/latest/d32/d32_pro.html)

> :warning: **Aufgrund von Speicherbeschränkungen ist es mittlerweile zwingend erforderlich, ESP32 mit PSRAM zu verwenden.** Vor diesem Hintergrund müssen Sie sicherstellen, dass Ihr Entwicklungsboard über einen ESP32-WROVER verfügt. Und Sie sollten darauf achten, dass 16 MB Flash-Speicher zur Verfügung stehen (beides gilt für alle oben genannten Entwicklungsboards).

Optional kann eine [headphone-pcb](https://forum.espuino.de/t/kopfhoererplatine-basierend-auf-ms6324-und-tda1308/1099/)
an [ESPuino-mini 4L (SMD)](https://forum.espuino.de/t/espuino-mini-4layer/1661) angeschlossen werden .

Sie können Leiterplatten jedoch auch gerne selbst entwickeln. Beachten Sie jedoch auch hier, dass Ihr ESP32 PSRAM benötigt, um ESPuino ordnungsgemäß auszuführen.

## Erste Schritte

- [Viel mehr Dokumentation gibt es hier](https://forum.espuino.de/c/dokumentation/anleitungen/10).
- Sie müssen [Visual Studio Code](https://code.visualstudio.com/) von Microsoft installieren.
- Installieren Sie das [PlatformIO Plugin](https://platformio.org/install/ide?install=vscode) in [Visual Studio
  Code](https://code.visualstudio.com/) und schauen Sie sich unbedingt die
  [documentation](https://docs.platformio.org/en/latest/integration/ide/pioide.html).
  an . Eine Schritt-für-Schritt-Anleitung finden Sie
  [hier](https://randomnerdtutorials.com/vs-code-platformio-ide-esp32-esp8266-arduino/.)
- Installieren Sie [Git](https://git-scm.com/downloads) und erstellen Sie mit . eine Kopie („Klon“) meines Repositorys auf Ihrem lokalen Computer `git clone https://github.com/biologist79/ESPuino.git`. Mit Git können Sie Ihr lokales Repository ganz einfach auf dem neuesten Stand halten, ohne es kopieren und einfügen zu müssen. Um es auf dem neuesten Stand zu halten, führen Sie Folgendes aus `git pull origin master`. Weitere Informationen 
  [hier](https://stackoverflow.com/questions/1443210/updating-a-local-repository-with-changes-from-a-github-repository)
  und
  [hier](https://forum.espuino.de/t/espuino-in-platformio-anlegen-und-mit-git-aktuell-halten/891).
- (Optional) Installieren Sie [GitLens](https://marketplace.visualstudio.com/items?itemName=eamodio.gitlens)
  als Plugin (um erweiterte Git-Funktionen in VSCode zu haben).
- Da das Git-Repository nun lokal gespeichert ist, importieren Sie diesen Ordner als Projekt in Platformio.
- Wählen Sie die [gewünschte Umgebung](https://forum.espuino.de/t/projekt-und-profilwechsel-in-visual-studio-code/768) (z.B. lolin_d32_pro_sdmmc_pe).
- Bearbeiten Sie `src/settings.h` ntsprechend Ihren Anforderungen.
- Boardspezifische (`HAL`) Konfigurationsdatei bearbeiten (z. B. `settings-lolin_d32_pro_sdmmc_pe.h` für Lolin D32/D32 pro). Wenn Sie ein Board betreiben, das dort 
  nicht aufgeführt ist: Beginnen Sie mit `settings-custom.h` und ändern Sie es entsprechend Ihren Anforderungen. 
- Schließen Sie Ihr Entwicklungsboard über USB an, klicken Sie auf das Alien-Kopf-Symbol in der linken Seitenleiste, 
  wählen Sie die Projektaufgabe aus, die Ihrem gewünschten HAL entspricht, und führen Sie aus Upload and Monitor. 
  Alle notwendigen Bibliotheken werden automatisch abgerufen und die Kompilierung des Codes beginnt. Danach wird 
  Ihr ESP32 mit der Firmware geflasht. Abhängig von Ihrem Entwicklungsboard kann es erforderlich sein, eine Taste 
  zu drücken, damit ESP32 in den Flash-Modus wechselt (nicht erforderlich für Lolin32, D32 und D32 pro).
- Schauen Sie sich nun die serielle Ausgabe unten im Fenster von Visual Studio Code an. Beim ersten Start können 
  einige Fehlermeldungen erscheinen (im Zusammenhang mit fehlenden Einträgen in NVS). Keine Sorge, das ist einfach 
  normal. Stellen Sie jedoch sicher, dass die SD-Karte erkannt wird, da dies zwingend erforderlich ist!
- Wenn alles gut gelaufen ist, sollte ESPuino beim ersten Start einen Zugangspunkt öffnen und ESPuino bietet ein 
  Captive-Portal an, das auf Ihrem Computer angezeigt wird. Wenn das nicht der Fall ist, verbinden Sie sich mit 
  einem WLAN namens „ESPuino“ und geben Sie es `http://192.168.4.1` in Ihren Webbrowser ein. Geben Sie dort 
  (oder im Captive-Portal) die WLAN-Anmeldeinformationen und den Hostnamen ein. Nachdem Sie die Konfiguration 
  gespeichert haben, starten Sie ESPuino neu.
- Nach dem Neustart versucht ESPuino, sich Ihrem WLAN anzuschließen (mit den zuvor eingegebenen Anmeldeinformationen). 
  War dies erfolgreich, wird in der seriellen Konsole eine IP angezeigt. Über diese IP können Sie mit einem Webbrowser 
  auf die GUI von ESPuino zugreifen; Stellen Sie sicher, dass Sie Javascript zulassen. Wenn die mDNS-Funktion in aktiv ist
  `src/settings.h`, können Sie anstelle der IP den konfigurierten Hostnamen erweitert um .local verwenden. Sie können also 
  `http://espuino.local` für Web-GUI und FTP verwenden.
- Über FTP und Web-GUI können Sie Daten hochladen (erwarten Sie einen Durchsatz von 320 kB/s bis zu 700 kB/s).
- Bei Bedarf muss FTP nach dem Booten aktiviert werden! Vergessen Sie nicht, eine Aktion zuzuweisen 
  `ENABLE_FTP_SERVER` in `settings.h` um sie aktivieren zu können. Neopixel blinkt grün (1x), wenn die Aktivierung 
  erfolgreich war. Es wird nach dem nächsten Neustart automatisch deaktiviert. Bedeutet: Sie müssen es jedes Mal 
  aktivieren, wenn Sie es benötigen (wenn zwischendurch ein Neustart erfolgte). Klingt nervig und ist es vielleicht 
  auch, aber es wird auf diese Weise ausgeführt, um mehr Heap-Speicher (für Webstream) zur Verfügung zu haben, wenn 
  FTP nicht benötigt wird.
- Über den Webbrowser können Sie verschiedene Einstellungen konfigurieren und RFID-Tags mit Aktionen verknüpfen. 
  Wenn die MQTT/FTP-Unterstützung nicht kompiliert wurde, werden ihre Konfigurationsregisterkarten nicht angezeigt.

## SD-card: SPI or SD-MMC (1 bit)-mode?

Es ist zwingend erforderlich, dass die SD-Karte funktioniert. ESPuino startet nicht ohne funktionierende SD-Karte (zumindest sofern dies `NO_SDCARD` aktiviert wurde). Es stehen jedoch zwei Modi für die Schnittstelle zu SD-Karten zur Verfügung: SPI und SDMMC (1 Bit). Beachten Sie, dass SDMMC doppelt so schnell ist wie SPI und einen GPIO weniger benötigt. Im Grunde ist es also ein Kinderspiel.

## Welcher RFID-Leser: RC522 oder PN5180?

RC522 ist sozusagen der ESPuino-Standard. Es ist günstig und funktioniert, allerdings müssen RFID-Tags in der Nähe des Lesegeräts angebracht werden. PN5180 hat stattdessen eine bessere RFID-Reichweite/-Empfindlichkeit und kann auch ISO-15693/iCode SLIX2-Tags, auch bekannt als „Tonies“, lesen (Sie benötigen ein Passwort, um Tonies zu lesen). Sie können ESPuino auch mit einer ISO-14443-Karte aktivieren (nachdem Sie PN5180 mit einer neuen Firmware geflasht haben). Diese Funktion wird LPCD genannt. Nachteile PN5180: Es ist teurer und benötigt mehr GPIOs (6/7 statt 4). Meiner Meinung nach lohnt es sich! Weitere Informationen finden Sie im Abschnitt zur Verkabelung des PN5180 weiter unten. Hinweis: Wenn Sie nur 3,3 V verwenden, achten Sie darauf, diese 3,3 V an die 5 V UND 3,3 V des PN5180 anzuschließen. Klingt seltsam, ist aber notwendig.

## 3.3 V oder 5 V?

ESP32 läuft nur mit 3,3 V. Aber was ist mit der Peripherie?

- 3,3 V! Denn: Wenn Sie den Batteriebetrieb mit LiPo/LiFePO4 planen, stehen keine 5 V zur Verfügung (es sei denn, USB ist angeschlossen oder Sie verwenden einen Aufwärtswandler). Deshalb liegt mein Fokus nur auf 3,3 V. Wenn Sie stattdessen 5 V verwenden möchten, tun Sie dies. Beachten Sie jedoch, dass dies möglicherweise nicht mit dem Batteriemodus kompatibel ist.
- MAX98357A: Bietet mehr Leistung bei 5 V, läuft aber auch bei 3,3 V. Wie auch immer: Es ist immer noch laut genug (meiner Meinung nach).
- Neopixel: Laut Spezifikation benötigt es 5 V, läuft aber auch mit 3,3 V.
- RC522: benötigt 3,3 V (niemals mit 5 V betreiben!)
- PN5180: Stellen Sie bei 3,3 V sicher, dass sowohl die 5-V- als auch die 3,3-V-Pins mit 3,3 V verbunden sind.
- SD-Karte: benötigt 3,3 V, kann aber auch an 5 V angeschlossen werden, wenn ein Spannungsregler vorhanden ist
- Drehgeber: 3,3 V (nicht mit 5 V versorgen! Dem Encoder ist es egal, ob er an 3,3 oder 5 V angeschlossen ist, aber GPIOs von ESP32 schon!)

## WiFi

Für Web-GUI, FTP, MQTT und Webradio ist WLAN zwingend erforderlich. Allerdings kann WLAN vorübergehend oder dauerhaft deaktiviert werden (und ESPuino merkt sich diesen Zustand nach dem nächsten Neustart). Es gibt zwei Möglichkeiten, WLAN (wieder) zu aktivieren/deaktivieren:

- erwenden Sie eine spezielle  [Modifikationskarte]  (https://forum.espuino.de/t/was-sind-modifikationskarten/37) , die über die Web-GUI konfiguriert werden kann.
- Weisen Sie einer Schaltfläche (oder einer Mehrfachschaltfläche) die Aktion `CMD_TOGGLE_WIFI_STATUS` zu . Dadurch wird der aktuelle WLAN-Status umgeschaltet.

## Bluetooth

> :warning: **Aufgrund von Speicherbeschränkungen ist es nicht möglich, Bluetooth parallel zu WLAN zu betreiben.** Das bedeutet, dass Sie kein Webradio über Bluetooth streamen oder auf die Web-GUI zugreifen können, während dieser Modus aktiviert ist.

### ESPuino als A2DP-Senke (Stream zu ESPuino)

ESPuino kann als Bluetooth-Senke (A2DP-Senke) verwendet werden. In diesem Modus können Sie Audio (z. B. von einem mobilen Gerät) über Bluetooth auf Ihren ESPuino streamen. Dieser Modus kann über eine RFID-Modifikationskarte oder durch Zuweisen einer Aktion `CMD_TOGGLE_BLUETOOTH_MODE` zu einer Taste (oder Mehrfachtaste) aktiviert/deaktiviert werden. Wenn Sie dies anwenden, wird ESPuino sofort neu gestartet. Aktiviertes Bluetooth wird durch vier langsam rotierende blau-violette LEDs angezeigt. Nachdem das Bluetooth-Gerät gekoppelt wurde, leuchten die LEDs blau.

### ESPuino als A2DP-Quelle (Stream von ESPuino)

ESPuino kann auch zum Streamen von Audio (A2DP-Quelle) an ein Bluetooth-Headset oder externe Bluetooth-Lautsprecher verwendet werden. Dieser Modus kann über eine RFID-Modifikationskarte oder durch Zuweisen einer Aktion `CMD_TOGGLE_BLUETOOTH_SOURCE_MODE` zu einer Taste (oder Mehrfachtaste) aktiviert/deaktiviert werden. Wenn Sie dies anwenden, wird ESPuino sofort neu gestartet. Aktiviertes Bluetooth wird durch vier langsam rotierende blau-violette LEDs angezeigt. Nachdem das Bluetooth-Headset verbunden ist, leuchten die LEDs blau.

## Port-Expander

Es kann Situationen geben, in denen Ihnen die GPIOs ausgehen. Um diesem Problem zu begegnen, kann ein Port-Expander [PCA9555](https://www.nxp.com/docs/en/data-sheet/PCA9555.pdf) erwendet werden, um die Anzahl der Eingangskanäle zu erweitern (der Ausgangsmodus wird nur in Sonderfällen unterstützt). PCA9555 bietet 2 Ports mit jeweils 8 Kanälen – also insgesamt 16 Kanäle. Um PCA9555 zu aktivieren, müssen Sie aktivieren
`PORT_EXPANDER_ENABLE`. Wie GPIOs in Ihrer entwicklungsboardspezifischen Einstellungsdatei können Sie Nummern zuweisen. Der Bereich ist 100(Port 0 Kanal 0) -> `115` (port 1 channel 7). (Port 1 Kanal 7). Über expanderI2cAddressden Port-Expander kann die I2C-Adresse geändert werden. Dies geschieht `0x20` wenn die Pins `A0`, `A1`, `A2` mit GND verbunden sind.

## Nachdem ESPuino mit Ihrem WLAN verbunden ist

Nachdem Sie ESPuino zu einem Teil Ihres LANs/WLANs gemacht haben, ist die „normale“ Web-GUI unter der von Ihrem Router zugewiesenen IP (oder dem konfigurierten Hostnamen) verfügbar. Mit dieser GUI können Sie:

- Das WLAN konfigurieren
- Verknüpfungen zwischen RFID-Tag, Datei/Verzeichnis/URL und Wiedergabemodus erstellen
- Bindungen zwischen RFID-Tag und einem Modifikationstyp herstellen
- MQTT konfigurieren (falls aktiviert)
- FTP konfigurieren (falls aktiviert)
- Konfigurieren Sie die Anfangslautstärke, die maximale Lautstärke (Lautsprecher/Kopfhörer), die Helligkeit von Neopixel (Nachtmodus/Standard) und die Inaktivitätszeit
- Konfigurieren Sie die Spannungspegel für den Batteriemodus
- Protokolle / Status / aktuelle Spur anzeigen
- Kontrollspieler
- Modifikationen ausführen (z. B. Modifikationskarte)
- Audiodateien hochladen (Webübertragung genannt)
- OTA-Updates durchführen (ESP32 nur mit 16 MB Flash-Speicher)
- NVS-RFID-Zuweisungen importieren + löschen
- ESPuino neu starten + herunterfahren

> :information_source: Wenn Sie einen RFID-Tag am RFID-Lesegerät anbringen, wird die entsprechende ID automatisch an die GUI übertragen. Es ist also nicht erforderlich, solche IDs manuell einzugeben (es sei denn, Sie möchten dies). Der Dateipfad wird automatisch durch Auswahl einer Datei/eines Verzeichnisses im Dateibrowser ausgefüllt.

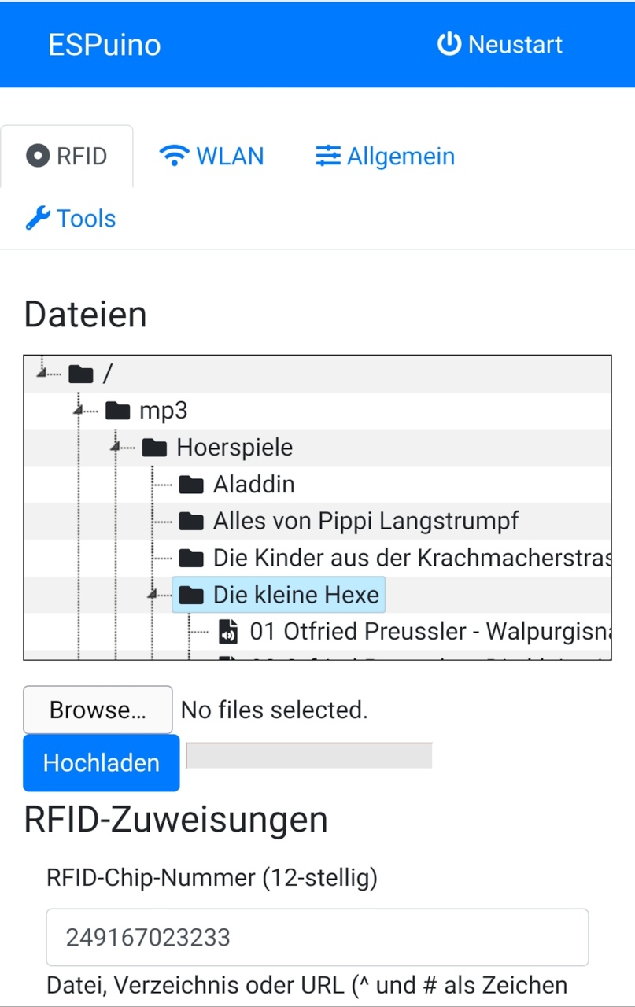
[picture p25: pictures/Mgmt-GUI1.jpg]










## Interaktion mit ESPuino

### Wiedergabemodi
Es geht nicht einfach nur darum, Musik zu spielen; Es werden verschiedene Wiedergabemodi unterstützt:

- `Single track` => spielt einen Titel einmal ab
- `Single track (loop)` => spielt einen Titel für immer ab
- `Single track of a directory (random). Followed by sleep` => wählt einen einzelnen Titel aus einem Verzeichnis aus, spielt ihn ab und schläft anschließend ein. Neopixel wird gedimmt.
- `Audiobook`=> einzelne Datei oder Playlist/Ordner; Die letzte Wiedergabeposition (Datei und Wiedergabeliste) wird gespeichert (beim Drücken der Pause-Taste oder beim Wechseln zu einem anderen Titel) und beim nächsten Mal wiederverwendet
- `Audiobook (loop)` =>  wie ein Hörbuch, aber in einer Endlosschleife
- `Folder/playlist (alph. sorted)` => spielt alle Titel in alph ab. Einmalig aus einem Ordner bestellen
- `Folder/playlist (random order)` => spielt alle Titel eines Ordners einmal in zufälliger Reihenfolge ab
- `Folder/playlist (alph. sorted)` => spielt alle Titel in alph ab. Bestellen Sie für immer aus einem Ordner
- `Folder/playlist (random order)` => spielt alle Titel in zufälliger Reihenfolge aus einem Ordner für immer ab
- `All tracks of a random subdirectory (sorted alph.)` => spielt alle Titel in zufälliger Reihenfolge aus einem Ordner für immer ab
- `All tracks of a random subdirectory (random order)` => spielt alle Titel in zufälliger Reihenfolge eines zufällig ausgewählten Unterverzeichnisses eines bestimmten Verzeichnisses ab
- `Webradio` => immer nur ein „Track“: spielt einen Webstream ab
- `List (files from SD and/or webstreams) from local .m3u-File` =>  kann eine oder mehrere Dateien/Webradiosender mit lokaler .m3u als Quelldatei sein

### Modifikation von RFID-Tags
Es gibt spezielle RFID-Tags, die Musik nicht von selbst starten, sondern Dinge verändern können. Bei einer zweiten Anwendung wird die vorherige Aktion/Änderung rückgängig gemacht.

Stellen Sie also zunächst sicher, dass Sie die Musik starten, und verwenden Sie dann eine Modifikationskarte, um die gewünschte Modifikation anzuwenden:

- Alle Tasten sperren/entsperren
- Schlafen Sie nach 5/30/60/120 Minuten
- Ruhezustand nach Ende des aktuellen Titels
- Nach Ende der Playlist schlafen
- Schlafen Sie nach fünf Titeln
- Neopixel dimmen
- Wiederhole Titel
- Wiederhole Playlist
- WLAN umschalten (aktivieren/deaktivieren) => Wenn Sie WLAN deaktivieren, während der Webstream aktiv ist, wird ein laufender Webstream sofort gestoppt!
- Bluetooth-Senke umschalten (aktivieren/deaktivieren) => ESPuino wird sofort neu gestartet. In diesem Modus können Sie über BT auf Ihren ESPuino streamen.
- Bluetooth-Quelle umschalten (aktivieren/deaktivieren) => ESPuino wird sofort neu gestartet. In diesem Modus kann Ihr ESPuino über BT an ein externes Gerät streamen.

> :information_source: Alle Schlafmodi dimmen (Neopixel) automatisch, da es abends beim Zubettgehen verwendet werden soll. Naja, zumindest ist das der Hinweis meiner Kinder :-)
>
> :information_source: Der Track- und Playlist-Loop-Modus kann gleichzeitig aktiviert werden, aber solange der Track-Loop nicht deaktiviert ist, ist der Playlist-Loop nicht wirksam

### Neopixel-LEDs (optional)

Zeigt verschiedene Dinge an. Vergessen Sie nicht, die Anzahl der LEDs über zu konfigurieren #define NUM_LEDS. Die meisten Designs verwenden einen Neopixel-Ring, aber auch ein linearer Streifen ist möglich.

> :information_source: Einige Neopixel verwenden eine umgekehrte Adressierung, was zu dem „Problem“ führt, dass alle Effekte gegen den Uhrzeigersinn angezeigt werden. Wenn Sie dieses Verhalten ändern möchten, aktivieren Sie einfach `NEOPIXEL_REVERSE_ROTATION`.

#### Boot

- Beim Booten: jede zweite LED (rotierend orange)
- SD kann nicht gemountet werden: LEDs blinken rot (bleibt für immer, es sei denn, die SD-Karte ist verfügbar oder `SHUTDOWN_IF_SD_BOOT_FAILS` ist aktiv)

#### Status

- **Leerlauf**: Vier LEDs drehen sich langsam (weiß, wenn WLAN verbunden ist; grün, wenn WLAN deaktiviert ist oder ESPuino gerade eine WLAN-Verbindung herstellt)
- **Bluetooth**: vier langsam rotierende LEDs in blauer Farbe
- **Fehler**: Alle LEDs blinken rot (1x), wenn eine Aktion nicht akzeptiert wurde
- **OK**: Alle LEDs blinken grün (1x), wenn eine Aktion akzeptiert wurde
- **Ausschalten**: Roter Kreis, der wächst, bis die lange Druckzeit erreicht ist
- **Tasten gesperrt**: Titel-Fortschritts-LEDs rot gefärbt

#### Wiedergabe

- **Warten**: violett; vier schnell rotierende LEDs beim Erstellen einer Playlist. Die Dauer hängt von der Anzahl der Dateien in Ihrer Playlist ab.
- **Titel-Fortschritt**: Regenbogen; Anzahl der LEDs im Verhältnis zum Spielfortschritt
- **Playlist-Fortschritt**: blau; erscheint im Playlist-Modus nur kurz mit Beginn jedes neuen Titels; Anzahl der LEDs im Verhältnis zum Fortschritt
- **Webstream**: zwei langsam rotierende LEDs, die im Verlauf des Streams ihre Farben regenbogenartig ändern
- **Laurstärke**: grün => rot-Farbverlauf; Anzahl der LEDs im Verhältnis zur aktuellen bis zur maximalen Lautstärke
- **Paused**: Track-Fortschritts-LEDs färben sich orange
- **Rücklauf**: Wenn die Einzelspurschleife aktiviert ist, wird beim Neustart des angegebenen Titels ein LED-Rücklauf durchgeführt

#### Batteriestatus (optional)

- **Unterspannung**: blinkt dreimal rot, wenn die Batteriespannung zu niedrig ist. Dieser Spannungspegel kann über die GUI konfiguriert werden.
- Durch kurzes Drücken der Taste des Drehgebers wird die Batteriespannung über Neopixel angezeigt. Ober- und Unterspannungsabschaltungen können per GUI eingestellt werden. Wenn beispielsweise die Unterspannung auf 3,2 V und die Oberspannung auf 4,2 V eingestellt ist, zeigen 50 % der LEDs eine Spannung von 3,7 V an.

### Tasten

> :warning: In diesem Abschnitt wird mein Standarddesign beschrieben: 3 Tasten + Drehgeber. Fühlen Sie sich frei, die Anzahl der Schaltflächen (bis zu 5) und Schaltflächenaktionen entsprechend Ihren Anforderungen und  `settings.h` Ihrer entwicklungsboardspezifischen Konfigurationsdatei (z. B. `settings-lolin32.h`). zu ändern. Es können maximal fünf Tasten + Drehgeber aktiviert werden. Die Mindestdauer für langes Drücken (zur Unterscheidung vom kurzen Drücken) in ms wird durch definiert `intervalToLongPress`. Alle verfügbaren Aktionen sind in aufgeführt `src/values.h`. Wenn Sie GPIO >= 34 verwenden, stellen Sie sicher, dass Sie einen externen Pullup-Widerstand (10 k) hinzufügen.

- **Vorherige (kurz):** vorheriger Titel / Anfang des ersten Titels, wenn gedrückt, während der erste Titel abgespielt wird
- **Vorheriger (lang):** erster Titel der Playlist
- **Nächster (kurz):** nächster Titel der Playlist
- **Nächster (lang):** letzter Titel der Playlist
- **Pause/Play (kurz o. lang):** Pause/Play
- **Drehgeber (drehen):** Lautstärke +/-
- **Drehgeber (lang drücken):** ausschalten (nur wenn an)
- **Drehgeber (kurz drücken):** einschalten (im ausgeschalteten Zustand)
- **Drehgeber (kurz drücken):** Batteriespannung über Neopixel anzeigen (wenn eingeschaltet und
  `MEASURE_BATTERY_VOLTAGE` ist aktiv)
- **Vorherige und Nächster:** WLAN aktivieren/deaktivieren

### Musikwiedergabe

- Die Musikwiedergabe beginnt sofort, nachdem ein gültiger RFID-Tag angebracht wurde (sofern dieser ESPuino bekannt ist).
- Wenn `PLAY_LAST_RFID_AFTER_REBOOT` aktiviert, merkt sich ESPuino die zuletzt angewendete RFID => Musik-Autoplay.
- Soll ein Ordner abgespielt werden, der viele MP3s enthält, kann die Erstellung der Playlist einige Sekunden dauern.
- Der Name einer Datei einschließlich Pfad darf 255 Zeichen nicht überschreiten.
- Während die Playlist generiert wird, zeigt Neopixel den Warten-Modus an.
- Nachdem der letzte Titel abgespielt wurde, zeigt Neopixel den Leerlauf-Modus an.

### Hörbuchmodus

Dieser Modus unterscheidet sich von den anderen, da die letzte Wiedergabeposition gespeichert wird, wenn...
- Der nächste Titel beginnt.
- erster/vorheriger/letzter Titel, der per Taste angefordert wird.
- Pause wurde gedrückt.
- Der Titel beendet ist.
- Die Wiedergabeliste ist zu Ende (die Position wird auf den ersten Titel und die Dateiposition 0 zurückgesetzt).
- Standardmäßig wird die letzte Wiedergabeposition beim Anbringen eines neuen RFID-Tags nicht gespeichert. Sie können dies aber mit `SAVE_PLAYPOS_WHEN_RFID_CHANGE` aktivieren.
- Standardmäßig wird die letzte Wiedergabeposition beim Herunterfahren nicht gespeichert. Sie können dies mit `SAVE_PLAYPOS_BEFORE_SHUTDOWN` aktivieren .

### FTP (optional)

- FTP muss nach dem Booten aktiviert werden! Vergessen Sie nicht, eine Aktion `ENABLE_FTP_SERVER` in `settings.h` zuzuweisen oder eine Modifikationskarte zu verwenden, um es zu aktivieren!
  Neopixel blinkt grün (1x), wenn die Aktivierung erfolgreich war. Es wird nach dem nächsten Neustart automatisch deaktiviert. Bedeutet: Sie müssen es jedes Mal aktivieren, wenn Sie es benötigen (wenn zwischendurch ein Neustart erfolgte). Klingt nervig und ist es vielleicht auch, aber es läuft auf diese Weise, um Heap-Speicher zu sparen, wenn FTP nicht benötigt wird.
- Warum FTP? Nun ja: Um nicht ständig die SD-Karte freizulegen oder ESPuino für das Hinzufügen neuer Musik zu zerlegen, ist es möglich, Musik per FTP auf die SD-Karte zu übertragen. Eine andere Möglichkeit besteht darin, dies über eine Web-GUI (Webtransfer) zu tun.
- DStandardbenutzer und Passwort sind auf `esp32` / `esp32` eingestellt, können aber über die GUI geändert werden.
- Gesichertes FTP ist nicht verfügbar. Stellen Sie daher sicher, dass SSL/TLS deaktiviert ist.
- Software: Meine Empfehlung ist [Filezilla](https://filezilla-project.org/), da es kostenlos und für mehrere Plattformen verfügbar ist.
- Bitte beachten Sie: Bei paralleler Musikwiedergabe sinkt diese Rate drastisch! Stoppen Sie daher besser die Wiedergabe, wenn Sie Dateiübertragungen durchführen.

### Energie sparen

Wie bereits im Abschnitt „Modifikationen“ beschrieben, stehen verschiedene Schlafmodi zur Verfügung. Zusätzlich wird der ESP32-Controller nach 10 Minuten Inaktivität in den Tiefschlaf versetzt (konfigurierbar über maxInactivityTime), es sei denn, ESPuino spielt keine Musik ab, hat einen angeschlossenen FTP-Client und keine Eingaben über Tasten. Bei jeder Tastenbetätigung wird der Zähler zurückgesetzt.

### Backups

Da alle Zuordnungen zwischen RFID-IDs und Aktionen (Wiedergabemodus, abzuspielende Datei usw.) im NVS des ESP gespeichert werden, besteht das Problem darin, dass alles verloren geht, wenn das ESP kaputt ist. Hier ist ein Backup also praktisch. Jedes Mal, wenn Sie über die GUI eine Zuordnung zwischen einem RFID-Tag und einer Aktion ändern oder eine neue hinzufügen, wird eine Sicherungsdatei auf der SD-Karte gespeichert. Der Name der Datei kann über `backupFile` geändert werden. Also besser nicht löschen! Mithilfe der Web-GUI können Sie das Upload-Formular verwenden, um eine solche Datei zu importieren.

### Smarthome/MQTT (optional)

Alles, was über RFID-Tags und -Tasten gesteuert werden kann, kann auch über MQTT gesteuert werden (mit Ausnahme des Umschaltens des WLAN-Status, da dies keinen Sinn ergibt). Alle manuellen Interaktionen (Tasten, RFID-Tags) werden auch parallel an MQTT gesendet, sodass alles immer synchron ist (es sei denn, die WLAN-/MQTT-Verbindung ist unterbrochen).

Um es nutzen zu können, muss ein MQTT-Broker ausgeführt werden. [Mosquitto](https://mosquitto.org/) zum Beispiel. Nach der Verbindung abonniert ESPuino alle Befehlsthemen. Statusthemen werden verwendet, um Status an den Broker zu senden, um andere zu informieren, wenn sich etwas geändert hat (Änderung der Lautstärke, neue Playlist, neuer Titel, was auch immer).

In meinem Heim-Setup verwende ich [openHAB](https://www.openhab.org/) um MQTT in einer schönen GUI zu „kapseln“, auf die über App + Web zugegriffen werden kann. Weitere Informationen (und Bilder) finden Sie im [openHAB directory](https://github.com/biologist79/ESPuino/tree/master/openHAB).

> :information_source: Ich habe eine Beispielkonfiguration für openHAB2  [beschrieben](https://github.com/biologist79/ESPuino/tree/master/openHAB). Mittlerweile ist jedoch openHAB3 verfügbar und alle beschriebenen Dinge können auch per GUI konfiguriert werden. Beachten Sie, dass openHAB ziemlich komplex ist und Sie einige Zeit aufwenden müssen, um sich damit vertraut zu machen.

#### MQTT topics

Nutzen Sie gerne Ihre eigenen Smarthome-Umgebungen (anstelle von openHAB). Die verfügbaren MQTT-Themen werden wie folgt beschrieben.

> :information_source: Wenn Sie einen Befehl an ESPuino senden möchten, müssen Sie ein cmnd-topic verwenden, während ESPuino seine Zustände über state-topics zurückschickt. Wenn Sie also die Lautstärke auf 8 ändern möchten, müssen Sie diese Nummer über topic-variable senden `topicLoudnessCmnd`. Unmittelbar danach sendet ESPuino eine Bestätigung dieses Befehls mit `topicLoudnessState`. Um MQTT in die Hände zu bekommen, empfehle ich dieses [als](https://www.hivemq.com/mqtt-essentials/) Einführung (deckt mehr ab, als Sie für ESPuino benötigen).

| topic-variable | range | Bedeutung |
| --- | --- | --- |
| topicSleepCmnd | 0 or OFF | Schalten Sie ESPuino sofort aus |
| topicSleepState | ON or OFF | Sendet den letzten Status von ESPuino |
| topicRfidCmnd | 12 digits | Legen Sie die Anzahl der RFID-Tags fest, die ein RFID-Tag „emuliert“ (z. B. 123789456089) |
| topicRfidState | 12 digits | ID des aktuellen RFID-Tags (falls keine Modifikationskarte) |
| topicTrackState | String | Sendet die aktuelle Titelnummer, die Gesamtzahl der Titel und den vollständigen Pfad des aktuellen Titels. ZB „(2/10) /mp3/kinderlieder/Ri ra rutsch.mp3“ |
| topicTrackControlCmnd | 1 -> 7 | `1`=stop; `2`=unused!; `3`=play/pause; `4`=next; `5`=prev; `6`=first; `7`=last |
| topicCoverChangedState  | | Zeigt an, dass sich das Titelbild möglicherweise geändert hat. Aus Leistungsgründen sollte die Anwendung das Bild nur laden, wenn es für den Benutzer sichtbar ist |
| topicLoudnessCmnd | 0 -> 21 | Lautstärke einstellen (abhängig von minVolume / maxVolume) |
| topicLoudnessState | 0 -> 21 | Sendet die Lautstärke (abhängig von minVolume / maxVolume). |
| topicSleepTimerCmnd | EOP | Nach Ende der Wiedergabeliste ausschalten |
| | EOT | Ausschalten nach Titelende |
| | EO5T | Ausschalten nach fünf Titeln |
| | 1 -> 2^32 | Dauer in Minuten bis zum Ausschalten |
| | 0 | Timer deaktivieren (falls aktiv) |
| topicSleepTimerState | various | Sendet aktiven Timer (`EOP`, `EOT`, `EO5T`, `0`, ...) |
| topicState | Online, Offline | `Online` beim Einschalten, `Offline` beim Ausschalten |
| topicCurrentIPv4IP | IPv4-string | Sendet die IP-Adresse von ESPuino (z. B. 192.168.2.78) |
| topicLockControlsCmnd | ON, OFF | Legen Sie fest, ob Bedienelemente (Tasten, Drehgeber) gesperrt werden sollen |
| topicLockControlsState  | ON, OFF | Wird gesendet, wenn Bedienelemente (Tasten, Drehgeber) gesperrt sind |
| topicPlaymodeState | 0 - 10 | Sendet den aktuellen Wiedergabemodus (Einzeltitel, Hörbuch...; siehe  [Widergabemodus](#playback-modes)) |
| topicRepeatModeCmnd | 0 - 3 | Wiederholungsmodus einstellen: `0`=no; `1`=track; `2`=playlist; `3`=both |
| topicRepeatModeState | 0 - 3 | Sendet den Wiederholungsmodus |
| topicLedBrightnessCmnd  | 0 - 255 | Stellen Sie die Helligkeit von Neopixel ein |
| topicLedBrightnessState | 0 - 255 | Sendet Helligkeit von Neopixel |
| topicBatteryVoltage | float | Spannung (z. B. 3,81) |
| topicBatterySOC | float | Aktuelle Batterieladung in Prozent (z. B. 83,0) |
| topicWiFiRssiState | int | Numerische WLAN-Signalstärke (dBm) |
| topicSRevisionState | String | Software-Revision |

## Entwicklung und Beiträge

### Codeformatierung

Es wird die automatische Codeformatierung über  `clang-format` verwendet. Die Konfiguration/Regeln finden Sie in `.clang-format`. Wenn Sie Visual Studio Code als IDE verwenden, ist die Unterstützung hierfür automatisch über die C++-Erweiterung verfügbar.

Verwenden Sie beim Bearbeiten des Quellcodes Strg+Umschalt+I, um die automatische Formatierung für die Datei auszuführen, oder Strg+K Strg+F für den ausgewählten Code.

Weitere Optionen über die automatische Formatierung beim Speichern oder Bearbeiten der Datei finden Sie in der [Dokumentation](https://code.visualstudio.com/docs/cpp/cpp-ide#_code-formatting).

Das CI (über „GitHub Actions“) prüft Änderungen beim Pushen, um den Quellcode sauber zu halten und den Entwicklern und Betreuern Feedback zu geben.

Um die Ausgabe `git blame` trotz der massiven Änderungen bei der Einführung neuer Formatierungsregeln sauber zu halten, haben wir eine `.git-blame-ignore-revs` Liste der zu ignorierenden Commits. In VSCode sollte dies automatisch verwendet werden, wenn Sie die Erweiterung „GitLens“ verwenden. Stellen Sie andernfalls sicher, dass Sie das Konfigurationsfragment für Git anwenden, indem Sie es  `git config --local include.path ../.gitconfig` einmal in Ihrem lokalen Klon ausführen.

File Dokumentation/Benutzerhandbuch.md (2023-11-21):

# Benutzerhandbuch
## Einführung
Eine Musikbox auf Basis des Open Source Projekt ESPunino von Torsten Stauder. Die vollständige Projektdokumentation gibt es unter [https://forum.espuino.de/](https://forum.espuino.de).
Für die dort beschriebene Hard- und Softwarelösung wurde ein kindgerechtes, kompaktes Gehäuse für den 3D-Drucker entwickelt und so entstand das Unikat Musikbox `Jolibox` als Geschenk zu ihrem 2. Geburtstag.

## Box mit eigenem WLAN verbinden
Zirkulieren nach dem Einschalten der Box die LED in grün, konnte die Box kein lokales WLAN-Netzwerk erkennen. Die Box eröffnet nun für die Konfiguration des WLAN ein eigenes HilfsWLAN mit der SSID: `JoliBox` ohne Passwort. 
Sobald Rechner/Handy mit diesem WLAN verbunden sind, kann im Browser die Adresse http://192.168.4.1 aufgerufen werden. In der Webseite können nun die Zugangsdaten zum eigenen WLAN eingegeben werden. 
Im Feld `SSID` und `Passwort` die Zugangsdaten zum eigenen WLAN eingeben. Um die Box nicht nur mit der IP-Adresse aufrufen zu können, ist im Feld `Hostname` ein Netzwerkname anzugeben (z.B. JoliBox).

## Weboberfläche
Nachdem die Box mit dem lokalen Netzwerk verbunden ist, kann die Steuerung der Box auch alternativ mit dem Browser erfolgen. 
Die Adresse der Box ist http://jolibox.fritz.box . Sollte dies nicht funktionieren, kann die Weboberfläche der Box auch mit seiner IP-Adresse angesprochen werden. Die aktuelle IP-Adresse kann mit der Tastenkombination `Zurück + Play/Pause` von der Box angesagt werden.

## Abspielen von Inhalten
Die Auswahl der abzuspielenden Titel erfolgt über die mitgelieferten RFID-Karten, oder weitere selbst programmierter RFID-Tags. 
Alternativ kann auch ein Ordner/Titel über die Weboberfläche gestartet werden. Hierzu im Browser im Register RFID den gewünschten Ordner/Titel im auswählen und über einen Rechtsklick den Menüpunkt `Abspielen` auswählen.
Auf der eingebauten SD-Karte sind bei Auslieferung nachfolgende Ordner gespeichert und mit jeweils einer Karte verknüpft. 
Diese Ordner können über die Weboberfläche der Box mit weiteren Titeln ergänzt werden. Auch neue Ordner mit neuen Titeln können jederzeit der Sammlung über die Weboberfläche hinzugefügt werden.
|Musik|Hörspiele|
|-----|---|
|Bewegungslieder 	(51 Lieder)	|Auf Traumreise mit Erwin der Ente 	(12 Folgen)
|Englische Kinderlieder 	(62 Lieder)	|Benjamin Blümchen 	(32 Folgen)
|Kindergartenlieder 	(48 Lieder)	|Kurzgeschichten 	(8 Folgen)
|Kinderlieder-Mix 	(173 Lieder)	|Leo Lausemaus 	(32 Folgen)
|Lieder für Krabbelkinder 	(153 Lieder)	|Maus-Hörspiel 	(133 Folgen)
|Lieder zum Mitmachen 	(40 Lieder)	|Petronella Apfelmus 	(27 Folgen)
|Rolf Zuckowski 	(150 Lieder)	|Unser Sandmännchen 	(79 Folgen)
|Schlaflieder 	(25 Lieder)		
|Spieluhr 	(66 Lieder)		
|Tierlieder 	(88 Lieder)		
|Unser Sandmännchen 	(97 Lieder)		
|Weihnachtslieder 	(34 Lieder	)	
|Zahnputzlieder 	(12 Lieder)		

##RFID-Tags zuordnen
Die RFID-Tags können über die Weboberfläche der Box zugeordnet werden. Hierzu die Weboberfläche aufrufen und dann ein RFID-Tag auf die Box legen. In der Registerkarte `RFID` wird nun die eindeutige Nummer des RFID-Tag angezeigt. Im oberen Teil der Webseite kann nun ein Ordner oder ein einzelner Titel ausgewählt werden. Anschließend über das DropDown-Menü einen `Abspielmodus` festlegen. Zum speichern der Einstellungen auf die Schaltfläche `Absenden` klicken.
Auf dieser Seite können bei Bedarf auch `Modifikationskarten` zur Funktionssteuerung der Box erstellt werden. Hierzu unten in den Tab `Modifikation` wechseln und im DropDown eine Funktion auswählen.

##Inhalte verwalten
Die Inhalte der Box können über die Weboberfläche oder alternativ über eine FTP-Verbindung verwaltet werden.
###Weboberfläche
- In der Registerkarte RFID kann der Inhalt der eingebauten SD-Karte verändert werden. 
Das Anlegen von neuen Ordnern und das Löschen von Ordner und Daten erfolgt über das Kontextmenü der rechten Maustaste.
- Neue Dateien können über die Schaltfläche `Dateien oder Ordner` ausgewählt, und dann mit der Schaltfläche `Upload` auf die Box in das gewählte Verzeichnis hochgeladen werden. 
Während des Upload sollte die Wiedergabe gestoppt werden, da es sonst zu Tonstörungen kommen kann und die Übertragungsgeschwindigkeit verringert wird.
Es gibt leider noch keine wirklich informative Fortschrittsanzeige, daher Geduld beim Upload.

###FTP
- Für eine FTP Verbindung zur Box muss zuerst der FTP-Server der Box eingeschaltet werden. Dies kann entweder über die Tastenkombination              innerhalb 30 Sekunden nach dem Einschalten Box, oder über die Weboberfläche erfolgen. Der FTP-Server bleibt dann bis zum nächsten Ausschalten der Box aktiv.
- Mit einem geeigneten FTP-Programm (z.B. WinSCP oder FileZilla) kann man sich nun mit der Box verbinden. Die Benutzerkennung und das Passwort lauten `esp32` Die Zugangskennung kann in der Weboberfläche bei Bedarf auch verändert werden.
- Das FTP-Programm zeigt nach der Anmeldung die vollständige Verzeichnisstruktur der eingebauten SD-Karte an und kann diese nach Belieben verändern.
## Akku laden
Im Boden der Box befindet sich die USB-C Ladebuchse. Zum Zeitpunkt der Auslieferung ist in der Ladebuchse ein Adapter für ein magnetisches Ladekabel eingesteckt. Dieser kann bei Bedarf auch herausgezogen werden und ein gewöhnliches USB-C Ladekabel zum Laden benutzt werden. Nach vollständiger Ladung erlöscht die Kontrollleuchte neben der Ladebuchse.
## Box zurücksetzen
Im Fehlerfall kann die Box mit einer Büroklammer in der gekennzeichneten Öffnung kurzzeitig stromlos gemacht werden und wieder in einen definierten Zustand versetzt werden. 
## Tastenbelegung
Die Box kann über einen Druck auf eine beliebige Taste eingeschaltet werden. Über einen langen Druck auf die rote Play/Pause Taste wird die Box ausgeschaltet. Sobald kein Titel mehr abgespielt wird schaltet die Box automatisch nach 10 Minuten ab.
Diverse Tastenkombinationen steuern das Abspielverhalten der Box.

|Taste  Tasten	|Kurzer Tastendruck	|Langer Tastendruck|
----------------|-------------------|------------------|
  |`Leiser`|Titel um 30 Sekunden vorspulen	|Lautstarke senken|
|`Zurück`|Vorheriger Titel in der Liste	|Letzter Titel der Playliste|
|`Play/Pause`|Start / Pause	|Box ausschalten|
|`Vor`|Nächster Titel in der Liste	|Erster Titel der Playliste|
|`Lauter`|Titel um 30 Sekunden zurückspulen 	|Lautstärke erhöhen|
|`Zurück` + `Vor`|Aktueller Titel wird endlos wiederholt|
|`Leiser` + `Vor`|LED auf Nachtmodus dimmen|
|`Play/Pause` + `Lauter`|Sleeptimer 30 Minuten und LED auf Nachtmodus dimmen (An / Aus)|
|`Vor` + `Lauter`|Schaltet den Bluetooth-Modus an/aus, bei dem man zur Box streamen kann (z.B. von einem Handy)|
|`Pay/Pause` + `Vor`|FTP-Server aktivieren zur Titelverwaltung über FTP. 
(Nur 30 Sekunden nach Einschalten zugelassen.)|
|`Zurück` + `Play/Pause`|IP-Adresse der Box ansagen|
|`Zurück` + `Lauter`|Keine Funktion|
|`Leiser` + `Play/Pause`|Keine Funktion|
|`Leiser` + `Zurück`|Keine Funktion|
|`Leiser` + `Lauter`|Keine Funktion (Wiedergabe an Bluetooth-Kopfhörer noch nicht möglich)|

> :information_source:  Diese Liste der Tastenbelegung ist auch an der Bodenplatte der Box angebracht.

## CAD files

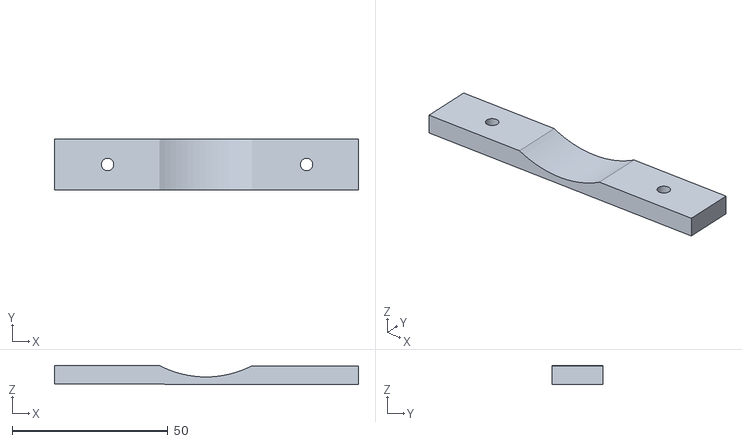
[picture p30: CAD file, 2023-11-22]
Dokumentation/Gehäuse/Tragegurtverschluss-unten.stl
97.6 x 16.5 x 6.22

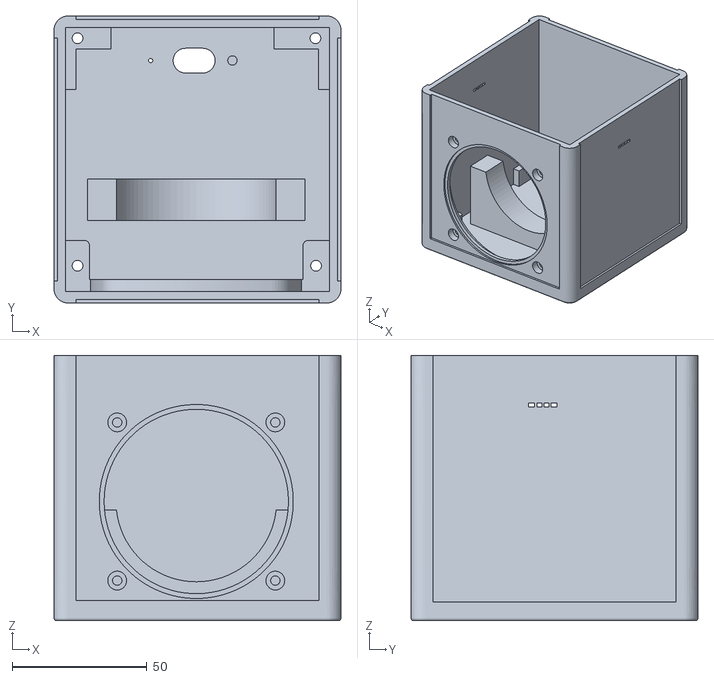
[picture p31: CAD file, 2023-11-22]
Dokumentation/Gehäuse/Gehäuse_Unterteil.stl
106.5 x 106.5 x 98.5

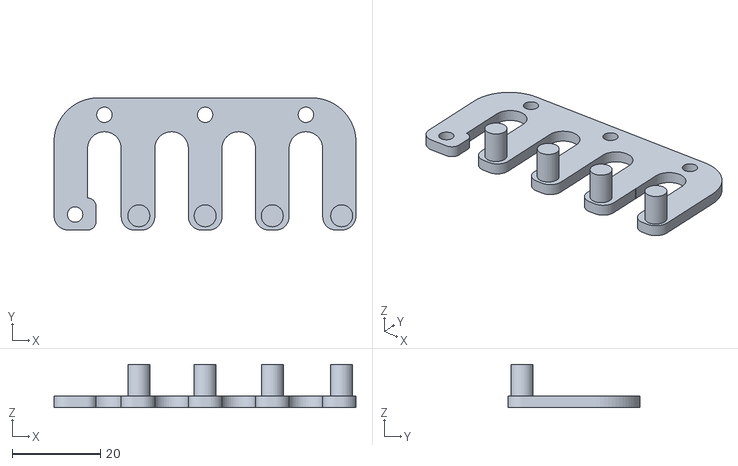
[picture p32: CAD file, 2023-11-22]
Dokumentation/Gehäuse/Tastaturhalter.stl
68.5 x 30.0 x 9.81

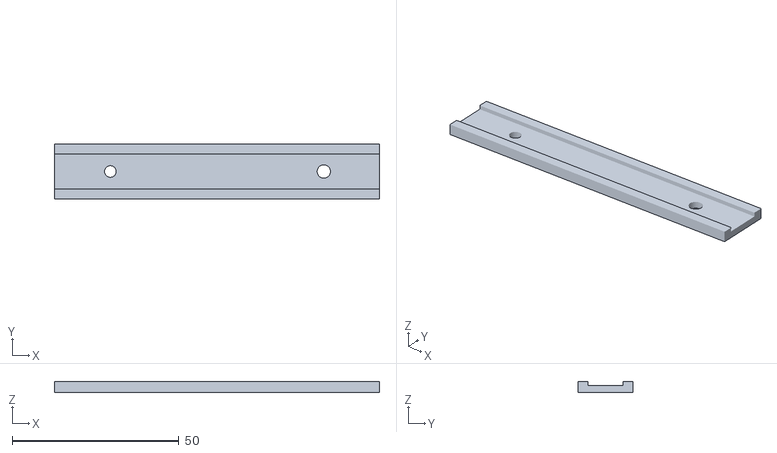
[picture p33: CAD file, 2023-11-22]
Dokumentation/Gehäuse/Tragegurtverschuss-oben.stl
97.3 x 16.5 x 3.20

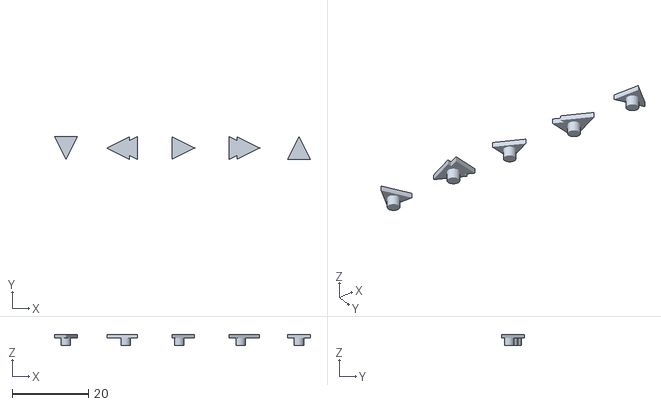
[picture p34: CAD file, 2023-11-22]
Dokumentation/Gehäuse/Symbole.stl
67.0 x 6.01 x 3.00

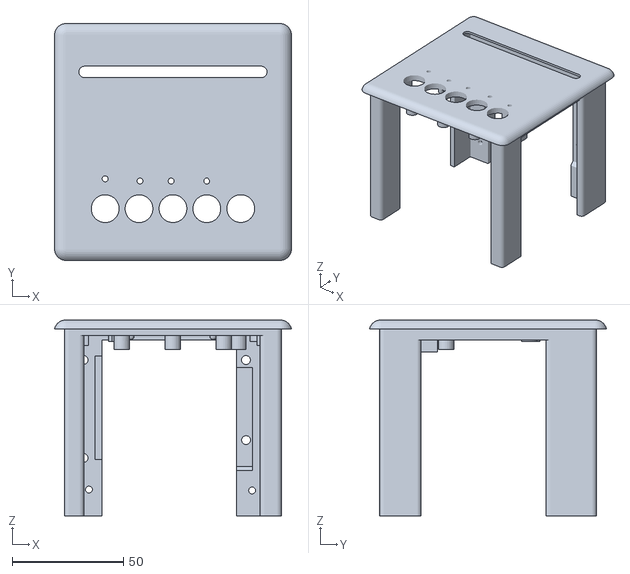
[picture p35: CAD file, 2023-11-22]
Dokumentation/Gehäuse/Gehäuse_Oberteil.stl
106.5 x 106.5 x 88.0

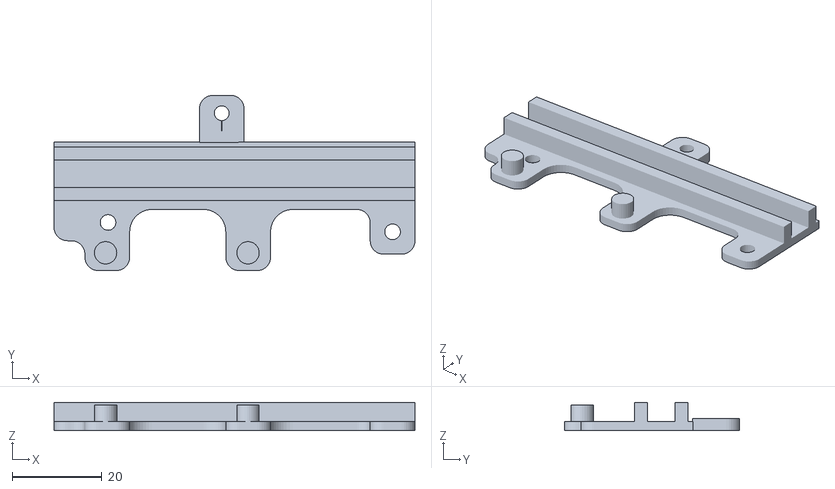
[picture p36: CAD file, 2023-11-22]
Dokumentation/Gehäuse/LED-Halter-Deckel.stl
80.6 x 39.1 x 6.30

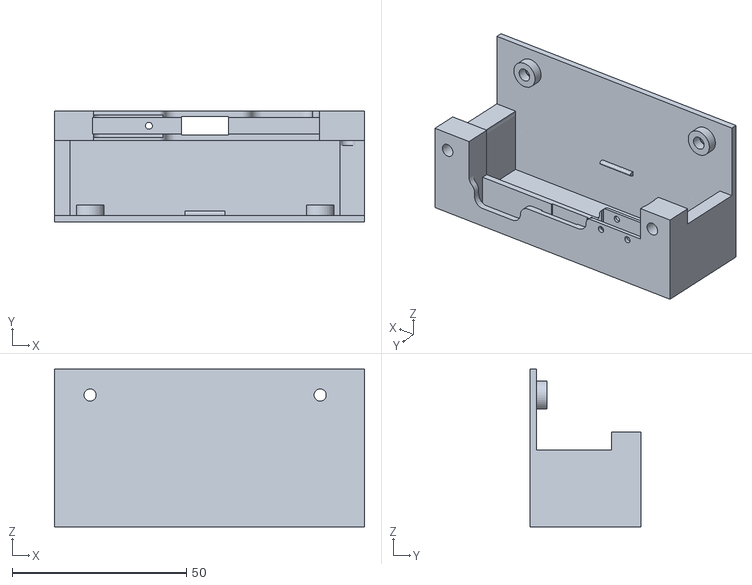
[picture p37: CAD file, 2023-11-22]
Dokumentation/Gehäuse/TrägerStromversorgung.stl
89.0 x 32.0 x 45.3

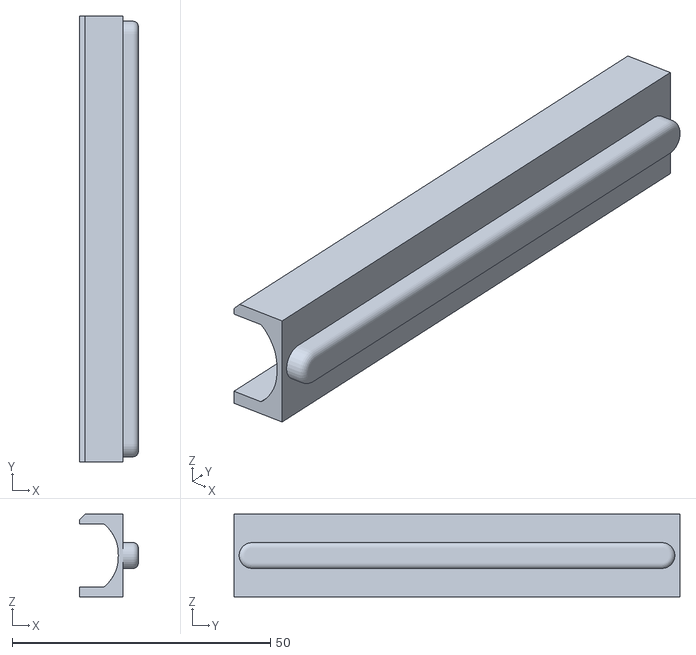
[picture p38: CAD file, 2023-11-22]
Dokumentation/Gehäuse/LED-Halter-Aussen.stl
11.4 x 86.4 x 16.0

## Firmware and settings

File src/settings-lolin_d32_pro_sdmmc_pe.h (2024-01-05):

// clang-format off

#ifndef __ESPUINO_SETTINGS_LOLIN_D32_PRO_H__
#define __ESPUINO_SETTINGS_LOLIN_D32_PRO_H__
    #include "Arduino.h"

    //######################### INFOS ####################################
    /* This is a PCB-specific config-file for *Wemos Lolin32 D32 pro with port-expander PCA9555PW and SD_MMC*.
    PCB: t.b.a.
    Forum: https://forum.espuino.de/t/espuino-minid32-pro-lolin-d32-pro-mit-sd-mmc-und-port-expander-smd/866
    Infos: https://www.wemos.cc/en/latest/d32/d32_pro.html
    Schematics Lolin D32 pro: https://www.wemos.cc/en/latest/_static/files/sch_d32_pro_v2.0.0.pdf
    Schematics PCB: t.b.a.
    Caveats: GPIO35 (battery monitoring) + don't use internal SD-slot as it's to capable of SD_MMC because of its pin-layout!
    Status:
        tested with PN5180 + SD_MMC (by biologist79)
    */

    //################## GPIO-configuration ##############################
    // Please note: GPIOs 34, 35, 36, 39 are input-only and don't have internal pullup-resistors.
    // So if connecting a button to these, make sure to add a 10k-pullup-resistor for each button.
    // Further infos: https://randomnerdtutorials.com/esp32-pinout-reference-gpios/
    // GPIOs 16+17 are not available for D32 pro as they're used to internal purposes (PSRAM).
    // All GPIOs >=100 and <= 115 are connected to a port-expander
    #ifdef SD_MMC_1BIT_MODE
        //  (MOSI)    15  CMD
        //  (SCK)     14  SCK
        //  (MISO)     2  D0
    #else
        // SPI-SD IS NOT SUPPORTED BY THIS PCB - DON'T USE INTERNAL SD-READER!
        #define SPISD_CS                    99          // GPIO for chip select (SD)
        #ifndef SINGLE_SPI_ENABLE
            #define SPISD_MOSI              99          // GPIO for master out slave in (SD) => not necessary for single-SPI
            #define SPISD_MISO              99          // GPIO for master in slave ou (SD) => not necessary for single-SPI
            #define SPISD_SCK               99          // GPIO for clock-signal (SD) => not necessary for single-SPI
        #endif
    #endif

    // RFID (via SPI)
    #define RST_PIN                         99          // Used as dummy for RC522
    #define RFID_CS                         21          // GPIO for chip select (RFID)
    #define RFID_MOSI                       23          // GPIO for master out slave in (RFID)
    #define RFID_MISO                       19          // GPIO for master in slave out (RFID)
    #define RFID_SCK                        18          // GPIO for clock-signal (RFID)

    #ifdef RFID_READER_TYPE_PN5180
        #define RFID_BUSY                   33          // PN5180 BUSY PIN
        #define RFID_RST                    22          // PN5180 RESET PIN
        #define RFID_IRQ                    99          // Depending on your configuration this needs to be adjusted to 32.
    #endif

    // I2S (DAC)
    #define I2S_DOUT                        25          // Digital out (I2S)
    #define I2S_BCLK                        27          // BCLK (I2S)
    #define I2S_LRC                         26          // LRC (I2S)

    // Rotary encoder
    #ifdef USEROTARY_ENABLE
        #define REVERSE_ROTARY                        // To reverse encoder's direction; switching CLK / DT in hardware does the same
        #define ROTARYENCODER_CLK           34          // rotary encoder's CLK
        #define ROTARYENCODER_DT            39          // 39 = 'VN'; rotary encoder's DT
    #endif

    // Amp enable (optional)
    #define GPIO_PA_EN                      108         // To enable/disable amp for loudspeaker; connected to port-expander

    // Control-buttons
    #define NEXT_BUTTON                     102         // Next-Button: connected to port-expander
    #define PREVIOUS_BUTTON                 100         // Prev-Button: connected to port-expander
    #define PAUSEPLAY_BUTTON                101         // Pplay-Button: connected to port-expander
    #define ROTARYENCODER_BUTTON            103         // Set to 99 to disable the button; connected to port-expander
    #define BUTTON_4                        104         // Button 4: connected to port-expander
    #define BUTTON_5                        105         // Button 5: connected to port-expander

    //#define BUTTONS_LED                   114         // Powers the LEDs of the buttons. Make sure the current consumed by the LEDs can be handled by the used GPIO

    // Channels of port-expander can be read cyclic or interrupt-driven. It's strongly recommended to use the interrupt-way!
    // Infos: https://forum.espuino.de/t/einsatz-des-port-expanders-pca9555/306
    #ifdef PORT_EXPANDER_ENABLE
        #define PE_INTERRUPT_PIN            36          // GPIO that is used to receive interrupts from port-expander + to wake up ESP32
    #endif
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

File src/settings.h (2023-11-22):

// clang-format off

#ifndef __ESPUINO_SETTINGS_H__
    	#define __ESPUINO_SETTINGS_H__
        #include "Arduino.h"
        #include "values.h"
#if __has_include("settings-override.h")
    	#include "settings-override.h"
#else
	//######################### INFOS ####################################
	// This is the general configfile for ESPuino-configuration.

	//################## HARDWARE-PLATFORM ###############################
	/* Make sure to also edit the configfile, that is specific for your platform.
	If in doubts (your develboard is not listed) use HAL 1
	1: Wemos Lolin32                        => settings-lolin32.h
	2: ESP32-A1S Audiokit                   => settings-espa1s.h
	3: Wemos Lolin D32                      => settings-lolin_D32.h
	4: Wemos Lolin D32 pro                  => settings-lolin_D32_pro.h
	5: Lilygo T8 (V1.7)                     => settings-ttgo_t8.h
	6: ESPuino complete                     => settings-complete.h
	7: Lolin D32 pro SDMMC Port-Expander    => settings-lolin_d32_pro_sdmmc_pe.h
	8: AZDelivery ESP32 NodeMCU             => settings-azdelivery_sdmmc.h
	9: Lolin D32 SDMMC Port-Expander        => settings-lolin_d32_sdmmc_pe.h
	99: custom                              => settings-custom.h
	more to come...
	*/
	#ifndef HAL             // Will be set by platformio.ini. If using Arduino-IDE you have to set HAL according your needs!
		#define HAL 1       // HAL 1 = LoLin32, 2 = ESP32-A1S-AudioKit, 3 = Lolin D32, 4 = Lolin D32 pro; ... 99 = custom
	#endif


	//########################## MODULES #################################
	#define PORT_EXPANDER_ENABLE          // When enabled, buttons can be connected via port-expander PCA9555 (https://forum.espuino.de/t/einsatz-des-port-expanders-pca9555/306)
	//#define I2S_COMM_FMT_LSB_ENABLE       // Enables FMT instead of MSB for I2S-communication-format. Used e.g. by PT2811. Don't enable for MAX98357a, AC101 or PCM5102A)
	#define MDNS_ENABLE                     // When enabled, you don't have to handle with ESPuino's IP-address. If hostname is set to "ESPuino", you can reach it via ESPuino.local
	//#define MQTT_ENABLE                   // Make sure to configure mqtt-server and (optionally) username+pwd
	#define FTP_ENABLE                      // Enables FTP-server; DON'T FORGET TO ACTIVATE AFTER BOOT BY PRESSING PAUSE + NEXT-BUTTONS (IN PARALLEL)!
	#define NEOPIXEL_ENABLE                 // Don't forget configuration of NUM_LEDS if enabled
	//#define NEOPIXEL_REVERSE_ROTATION     // Some Neopixels are adressed/soldered counter-clockwise. This can be configured here.
	#define LANGUAGE DE                     // DE = deutsch; EN = english
	//#define STATIC_IP_ENABLE              // DEPRECATED: Enables static IP-configuration (change static ip-section accordingly)
	#define HEADPHONE_ADJUST_ENABLE         // Used to adjust (lower) volume for optional headphone-pcb (refer maxVolumeSpeaker / maxVolumeHeadphone) and to enable stereo (if PLAY_MONO_SPEAKER is set)
	#define PLAY_MONO_SPEAKER             // If only one speaker is used enabling mono should make sense. Please note: headphones is always stereo (if HEADPHONE_ADJUST_ENABLE is active)
	#define SHUTDOWN_IF_SD_BOOT_FAILS       // Will put ESP to deepsleep if boot fails due to SD. Really recommend this if there's in battery-mode no other way to restart ESP! Interval adjustable via deepsleepTimeAfterBootFails.
	#define MEASURE_BATTERY_VOLTAGE         // Enables battery-measurement via GPIO (ADC) and voltage-divider
	//#define MEASURE_BATTERY_MAX17055      // Enables battery-measurement via external fuel gauge (MAX17055)
	//#define SHUTDOWN_ON_BAT_CRITICAL      // Whether to turn off on critical battery-level (only used if MEASURE_BATTERY_XXX is active)
	#define PLAY_LAST_RFID_AFTER_REBOOT   // When restarting ESPuino, the last RFID that was active before, is recalled and played
	//#define USE_LAST_VOLUME_AFTER_REBOOT  // Remembers the volume used at last shutdown after reboot
	#define USEROTARY_ENABLE                // If rotary-encoder is used (don't forget to review WAKEUP_BUTTON if you disable this feature!)
	#define BLUETOOTH_ENABLE                // If enabled and bluetooth-mode is active, you can stream to your ESPuino or to a headset via bluetooth (a2dp-sink & a2dp-source). Note: This feature consumes a lot of resources and the available flash/ram might not be sufficient.
	//#define IR_CONTROL_ENABLE             // Enables remote control (https://forum.espuino.de/t/neues-feature-fernsteuerung-per-infrarot-fernbedienung/265)
	//#define PAUSE_WHEN_RFID_REMOVED       // Playback starts when card is applied and pauses automatically, when card is removed (https://forum.espuino.de/t/neues-feature-pausieren-wenn-rfid-karte-entfernt-wurde/541)
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

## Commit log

2023-11-19 Übernahme espuino-master von biologist mit Stand 7.11.2023
    [custom_16mb_ota.csv, custom_4mb_noota.csv, custom_8mb_ota.csv]
2023-11-22 Gehäuse Beschreinbung
    [Gehäuse_Oberteil.stl, Gehäuse_Unterteil.stl, LED-Halter-Aussen.stl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]
